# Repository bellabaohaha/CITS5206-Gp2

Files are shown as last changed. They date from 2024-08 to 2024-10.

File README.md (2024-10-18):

# CITS5206-Gp2

The team predominantely used [Github Projects (Issues)]([url](https://github.com/bellabaohaha/CITS5206-Gp2/projects?query=is%3Aopen)) to document the provisioning, development, and testing of the solution as this was predominantly a hardware and cloud based project to keep the documentation consistent and source of information centralised. A client demonstration was completed and a report was created and sent to the client directly.

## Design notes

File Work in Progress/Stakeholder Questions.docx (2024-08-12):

# Stakeholder Questions

1. What is your current solution for soil compaction?
- Prompts: Do you send someone to the field to manually monitor or is there any other source of “ground truth”.
- Why: Eventually we may want to test and validate results for effectiveness and/or accuracy of IoT solution. Can also compare (time trial) how long the alternative takes
2. Do you currently track how much time you spend measuring soil moisture or dealing with the fall out (bogged equipment) of the effects of soil compaction?
- Why: So we can find out how much time, resources it takes, how often it occurs and good point of comparison. Goal is not to create more work when solving the problem.
3. Do you foresee any challenges with implementing IoT solution?
- Prompts: Would you be ok with dispersing these sensors. If an IoT solution is provided, can you place them so that your existing equipment will not ‘run over’ them.
4. When you open the map on John Deere Platform, for each paddock we imagine there will be multiple IoT Sensors, currently we’re thinking of sending through the Location data of the sensor and the last reported Soil Moisture level (early morning or midday).

Would you also like to have a recommendation on the John Deere Dashboard that suggest whether it’s safe to operate heavy machinery or not?

- Why: User Experience information so that we know what information is required and how best to display it. See Example below.

Example from John Deere Platform - Source (https://developer.deere.com/dev-docs/assets)

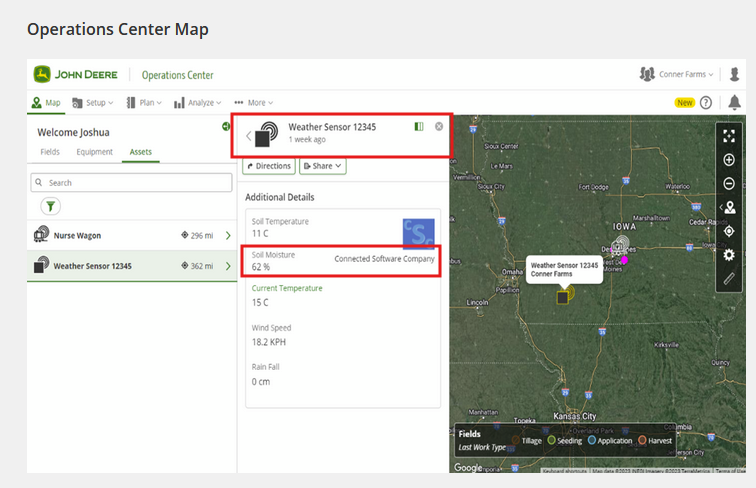
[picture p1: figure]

5. At this stage or any other stage of the project do you have any comments or things that we need to consider or any challenges that we may need to solve?

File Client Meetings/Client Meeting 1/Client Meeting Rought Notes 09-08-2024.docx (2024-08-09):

Agenda for Meeting:

1. Review John Deere Platform

Questions:

  a. What does the platform look like for the user

Farm, different paddocks and geometries. All equipment has telemetry data.

Decision support system. Every operation i.e. sprayer is shown on platform. Developer options has machinery and sensors. Goal is to have environment other sensor to platform and link it. And Display on the map. (Map section of Operations Center). Sensor streams data. Need to send an email

Telemetry data with real time RPM, fuel, idle time, time working under Maps.

One data under a team -> Setup has data.

Make a UWA account and send that through today.

Get letter from Atif and Gustavo if required.

Data is stored in ShapeFiles GIS data. Geometric

Target Rate -> Required rate of soil moisture, does that change over time over different prases

Manipulate through Irrigation System. Target rate from point of view. They used to sow seeds when there was rain, now they sow when dry, because they want optimal window of growing crops. Changing soil moisture in clay soil particularly in soil compaction problem

13-14% of WA has clay soils -> This is why soil compacts. Action: Pressure, deforms soil. Depends on resistance of terrain (sandy, clay) weight of equipment and down force is major factor. Large equipments (farm machinery western Australia)

Heavy machinery : Bourgalt heavy seeder – 17 tonnes without seed and fertiliser. They control it with trend lines and always be on the same track. Also waterlogging. Waterlogging can be visible and the effects can last even after the visible water level decreases. So we need to reach the right moisture level threshold. Top level of soil is sand, second layer is clay and the water gets trapped between two layers

Communication from sensor to API

John Deere has rainfall in mm, API for BOM available, PERSIANN CDR NOAA (out of scope) Package from Python or R package with deeper network of weather stations

GIS for geometry geo-fencing

Requirements for sending time based:
1. Twice a day

2. Early in the morning (stop for lunch)

3. Sampling rate (once an hour takes a reading)

4. Send through what we think requirement are

5. Areas we are covering, problem statement and quantification of impact. Get feedback

Next Steps:
1. Developer Account

2. Setup geo-fencing (GIS) and adding network

3. API

4. Send message to Rachel regarding network

5. LoRa limitation (mesh network using local raw LoRa with NB-IoT with a gateway)

Third parties currently source data from platform, process and send back to platform – we could use this for interpolation of the soil moisture data.

  b. What does landing page look like
  c. How would they normally check their assets
  d. Can you integrate other applications, ‘views’ or dashboards
  e. Besides operations do they manage anything else – trying to see if there is an opportunity for value add i.e. can we integrate with existing BOM rainfall data as a benchmark. OR do they manually collect the soil moisture that they want to view on the platform
2. Discuss questions we have for Farmer
- Ask Hani what we wrote down
3. Feedback for work we have completed
- Have them showcase in 1-2mins what they have done so far, get any feedback
  - David – Problem Statement
  - Bella – Quantifying Impact
  - Uday/Dharani – Initial Research into components
- List of Requirements 1. Number of Devices -?

2. Maximum and minimum distance between devices

3. What information is gathered and how often?

4.

- Solution Components:
1. Overall Considerations:
  a. Authentication of device
  b. Encryption (at rest vs in transit)
  c. Device and Software Setup + Calibration (Testing and Validation)
  d. Maintenance
  e. Deployment
  f. Retrieval
  g. Disposal
2. Physical Hardware Device:
  a. Soil Moisture Sensor(s)
  b. Microcontroller
  c. Power Storage
  d. Power Management
  e. Power Generation
  f. Communication Transceiver (how do we decide which one) – depends on transmission/communication pipeline
3. Transmission Pipeline (can we create a diagram, horizontal axis
  a. Between devices (node to node)

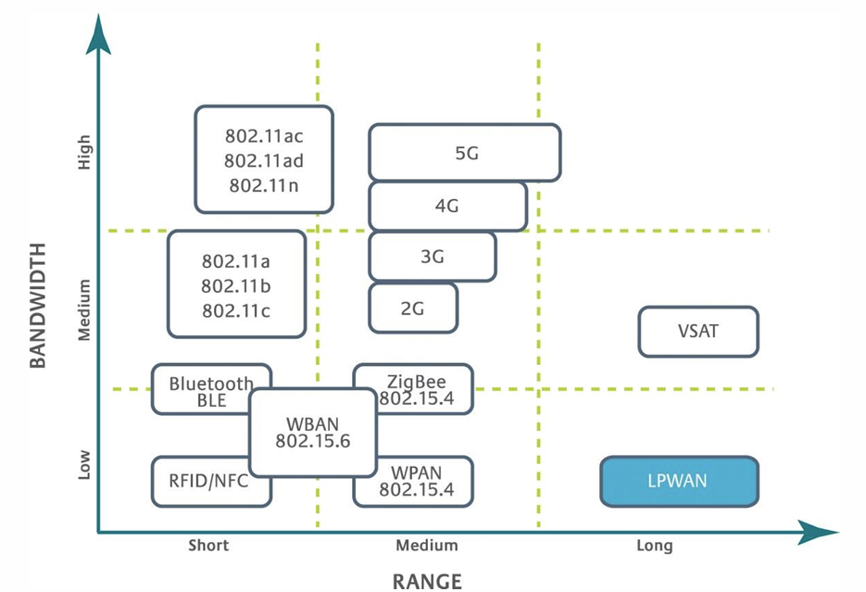
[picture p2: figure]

4. Discuss any bottlenecks or uncertainties
5. Discuss next steps
6. Book in next meeting

Handover and Post Handover Considerations

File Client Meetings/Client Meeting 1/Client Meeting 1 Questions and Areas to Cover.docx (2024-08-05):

Introductions

Gustavo – Rapid prototyping, sensing, agriculture

Wesley (Wess) – background as mechancial and technology sensors

Atif – Mainroads, bridge health monitoring

Highlight Risks

Don’t have anyone with an electrical, mechatronics, mechanical and agriculture background

Project Overview
After minining oil and gas, agriculture largest industry in WA

40% of grain exports comes from WA

Access to bunch of farmers.

Farmer needs to do bunch of operations during growing season

Problem: cannot operate heavy machinery during rain due to compaction + bogged

Average farm size is 6000 hectres

When it rains heavy machinery has issues – no real time monitoring in Satellite currently

Current solution – person on ground checks ground to see whether they can do their farming process with their machinery

Sensor requirements:

Soil monitoring at different depths, when a level of moisture is reached it sends a message

Constraints: Ruggedised sensor, calibrated for different types of soil, measuring conductivity (different soils influence calibration). LORA equipment run for scientific purposes are quite expensive. Any equipment is minimum $700, as we need to have multiple sensors especially in water logged areas. Current smart agriculture solutions are being offered by one platform for decision support service (John Deere) - can access their API etc.

What we need is a real time soil monitoring system + Dashboard and integrate with John Deere API – within the same platform. Still to decide on the sensor, it is quite complex. Each real time monitoring system will have multiple sensors at different depths. We need to focus on communication network, low power sensor and the integration as the sensor itself and ruggedising it is something that will have to be looked at with a team with proper capabilities.

Constraint is Time and our Capabilities - Major Milestones:

1. Project Specification – Lock in Meeting in Week 4 for feedback
2. Final Project Demonstration and Report – Lock in Meeting in Week 10 for demo and report

Action Steps

Find Challenges ushc as

- Integration with John deere API
- Capture soil moisture at different depths
- Managing power - low power
- Communication inside the ground
- Thesis
- Edge Computing (Farmer’s house, cellular connectivity), what type of data has to be
- What John Deere API payload looks like
- Dashboard User interface – is it a RAG indicator for point in space (GPS location) soil moisture, is it a reading of soil moisture, is there interpolation between sensors

Deliverable:

Overview of Design and Requirements

Document in a way it built upon

Power, appropriate microcontroller, What the data looks like, Commuication of it, and basic Protoype focus is Wireless Network, Power, and integrating to John Deere API

Focus on Design with small prototype and Simple soil moisture sensors

Define the requirements, then timeline and requirements

How to best communicate the dashboard output (user interface) on John Deere Platform – talk to a real farmer

Problem of finding the sensors and then also running over it etc.

John Deere Platform Farm to see how it works – Gustavo

Basically device sends telemetry data

Geospatial information and interpolation (need to consider this). Point based information for sensor, surface (inverse distance way so if 50 + 35, divide between it)

Overview of the problem, all the things we want and then perhaps a demonstration of a part of it with a basic prototype. Focus on project requirements. Defined documentation is also important

Before Next Meeting

- Goals
- Timeline of research
- Stakholders, and look at John Deere sensor (find out what it looks like on the dashboard)
- Research on communication tehcnology
- Required, every week: Send weekly update of what we have done

## Meeting Preparation:

Introductions

Go around table and understand everyone’s background and what their expertise is, so we know who might be the best person to contact for a particular issue or area of knowledge.

Client Role and Expectations

1. Roles – what are your roles for this project
  a. How involved do you want to be in the project development process? Can we do some research, get some feedback and iterate?
  b. Are there any other stakeholders we need to engage?
2. Expectations for meetings – Availability, Time
3. Communciation preference - Email and/or F2F/Teams Workshop
4. Expectation for final deliverable – What does it look like? One Soil Moisture monitoring system with some sensors, microcontroller, battery that sends data using a communication protocol to eventually connect to the internet and update a live dashboard to show insights into soil moisture and maybe make a recommendation based on a threshold or value?

Constraint is Time and our Capabilities - Major Milestones:

3. Project Specification – Lock in Meeting in Week 4 for feedback
4. Final Project Demonstration and Report – Lock in Meeting in Week 10 for demo and report

Project has a bit of breadth and depth. Goal is to provide you something valuable. Is this a prototype or an MVP? Because if we did it right and considered all the elements MVP will require significantly more time than time allows for. We could identify all the elements that we cannot complete and add into future works

Understanding Client's Needs and Expectations

1. Project Scope and Objectives:
  - What are the main goals of the soil moisture monitoring system?
  - Are there specific features or functionalities that are essential?
2. Current Practices and Challenges:
  - How do farmers currently monitor soil moisture?
  - What challenges do they face with the current methods?
  - Besides what is in the brief are there any specific problems related to soil compaction that need to be addressed?

Technical Requirements

3. Data Requirements:
  - What specific data points are crucial for effective soil moisture monitoring (e.g., soil moisture levels at various depths, temperature, humidity)?
  - Is there any analysis or transformation of data like an equation or something for soil moisture?
  - How frequently should the data be collected and reported?
4. Sensor Selection:
  - Are there any preferences or restrictions regarding the types of sensors to be used (e.g., cost, durability, accuracy)?
  - Are there specific depths at which soil moisture needs to be measured?
5. Environmental Considerations:
  - What environmental factors should be considered (e.g., waterproofing, resistance to rust, temperature range)?

Communication and Data Management

6. Read Omar’s paper before on Communication Technology, wanted to clarify:
  - Communication technology really depends on payload (data size). What communication technologies are feasible for transmitting data from the sensors to the local hub/server and then to the internet? NB-IoT or LoRAWAN might be easiest
7. Data Integration and Dashboard:
  - What attributes and metrics should be included in the dashboard?
  - Do you have any prefererence on how the data should be visualized to provide actionable insights for farmers?
  - Did you want us to integrate anything else into the dashboard – see link in my research

Cost and Implementation

8. Budget Constraints:
  - Are there any budget constraints or funding considerations for the project?

Analysis and Testing

9. Testing System accuracy and robustness:
  - I found capactative soil moisture sensor requires calibration etc. that will take time.
  - Hard to do this as we need commercial sensors – see research (we can simulate)

Miscellaneous

9. Regulatory and Compliance Issues:
  - Are there any regulatory requirements or compliance issues that need to be considered? E.g. we have to go off site to test or something

Clarifying Soil Compaction

- Ask about the relationship between soil moisture and soil compaction:
  - How do they currently measure or assess soil compaction?
  - Are there existing technologies or methods they use to monitor soil compaction?

Example Sensors and Technologies

- Discuss potential sensors and technologies that could be used from researc:
  - Capacitive or resistive soil moisture sensors for measuring moisture at different depths.
  - GPS modules for location information.
  - Wireless communication modules (e.g., LoRa, NBIoT) for data transmission

Summary of Meeting

Action Steps

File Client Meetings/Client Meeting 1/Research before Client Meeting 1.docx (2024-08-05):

Communication Paper Takeaway:

- Communication Protocol will probably be LoRaWAN or NB-IoT
- Really depends on the data that is being collected and transmitted

Waterlogging article:

- Costs approx $50M a year
- Issue for productivity
- Quite a complex problem, really still didn’t fully understand it
- There are existing solutions

John Deere Website:

- APIs available but not really specific e.g. weather station asset, environment etc.
- Need to clarify with Atif what he wants us to focus on here, is it an example JSON payload?

https://developer.deere.com/dev-docs/assets#type-table

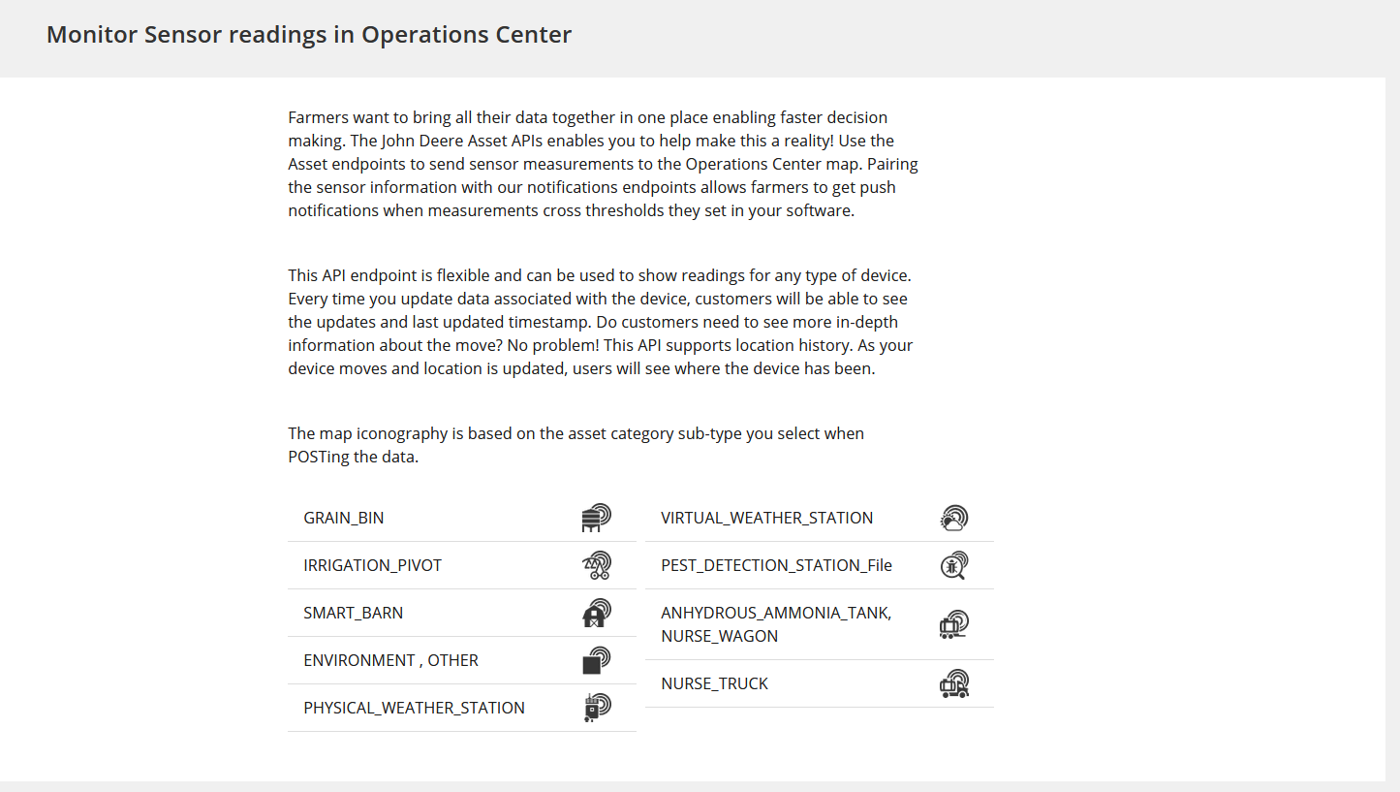
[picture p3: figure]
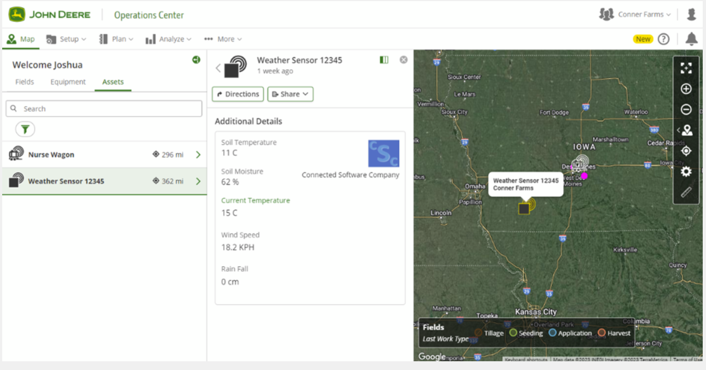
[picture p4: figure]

My Research

Article supporting usefulness of satellite soil moisture monitoring: https://www.mdpi.com/2072-4292/14/16/3971

Other estimates/sources for soil moisture:

1. Since 2021 - https://www.tern.org.au/news-smips-soil-moisture/; I think it’s ML derived fusion (Data assimilation) model. https://shiny.esoil.io/SMIPS/

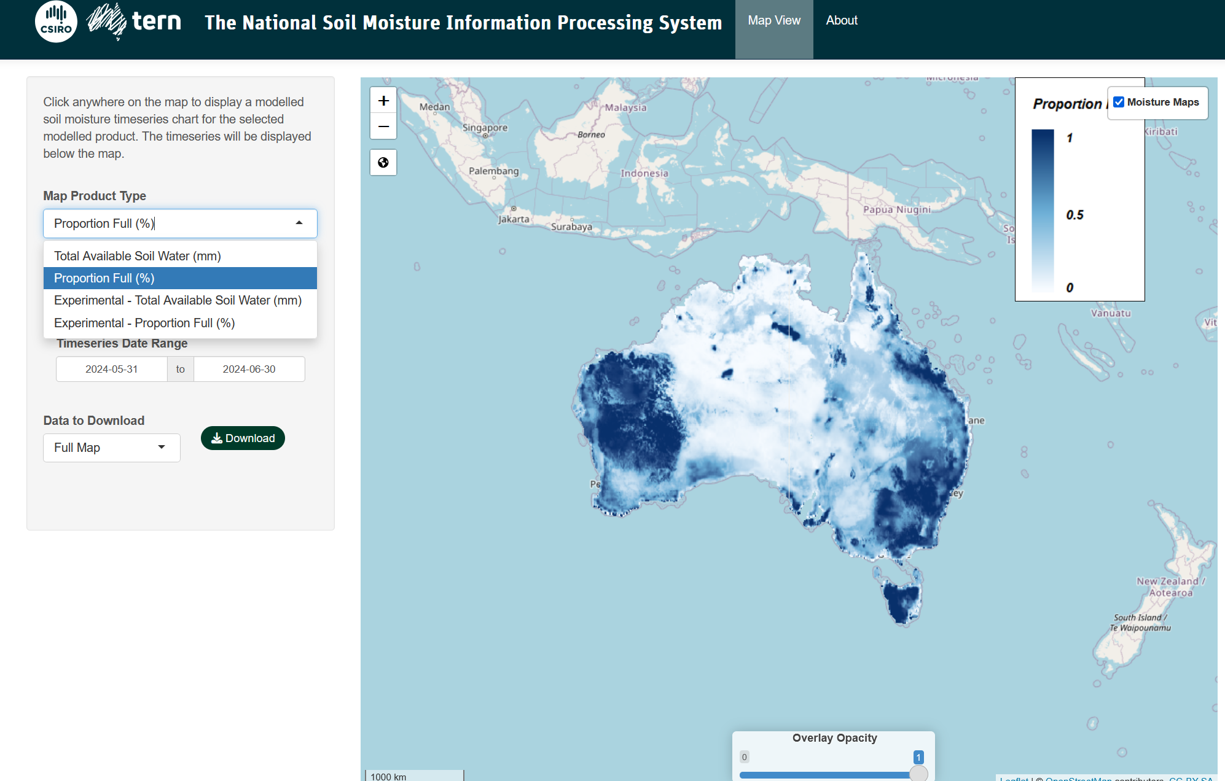
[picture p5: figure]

2. https://awo.bom.gov.au/products/historical/soilMoisture-rootZone/5,-27.489,134.231/nat,-25.609,134.362/r/d/2024-08-01

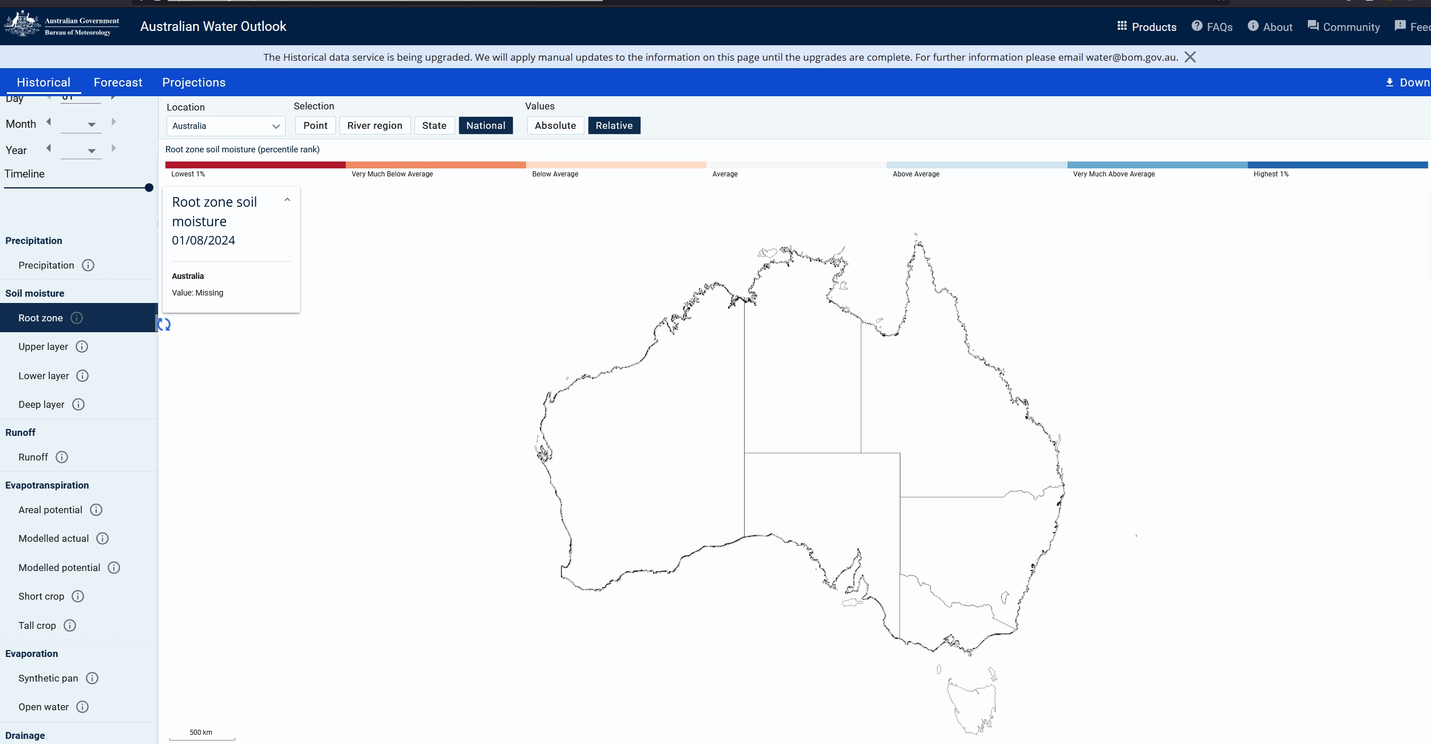
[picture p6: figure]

3. https://ausenv.tern.org.au/aex/#/2023/Soil_moisture/Region/Actual/Local_Government%20Areas/bar,options/-31.86/116.54/8/none/Roadmap/Opaque

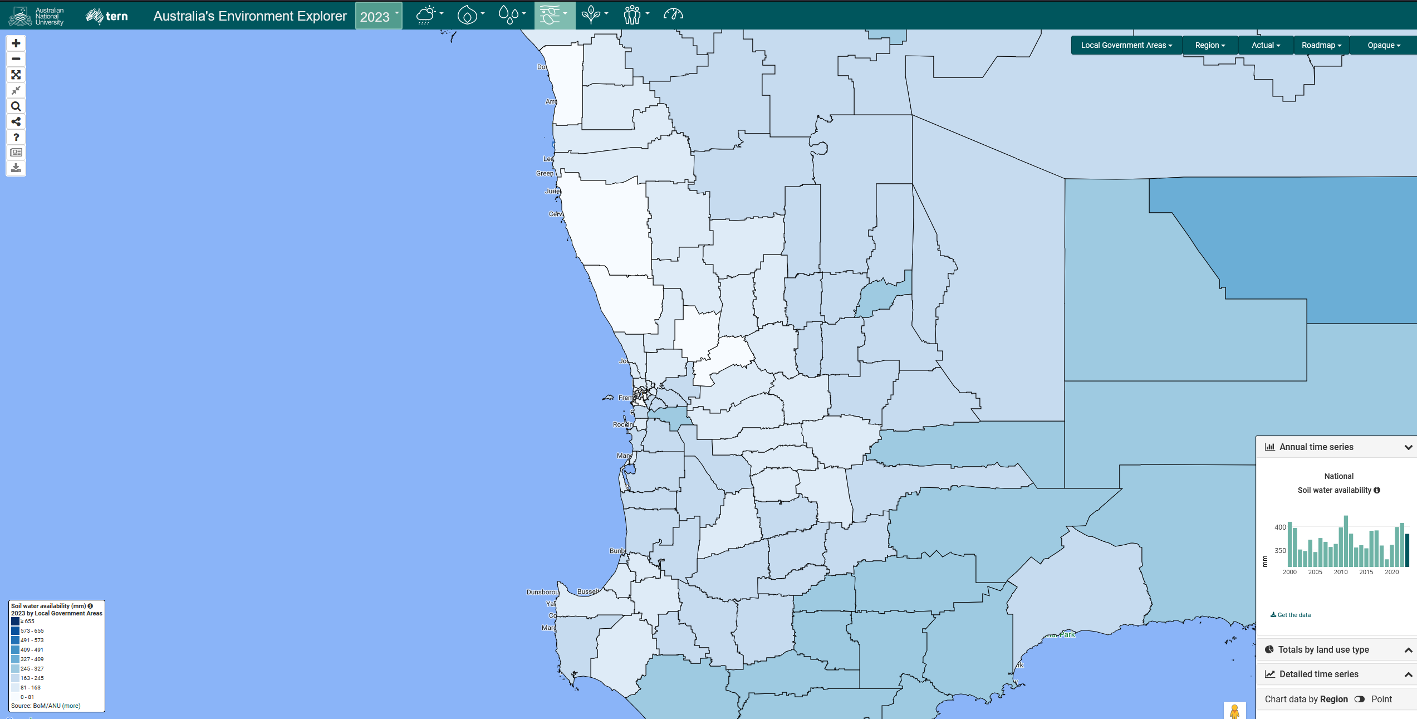
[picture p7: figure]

Appparently capacitative soil moisture sensors are better because of galvanic effect?

https://forum.arduino.cc/t/looking-for-a-proof-that-soil-moisture-sensors-can-be-reliable/662749

Found some resources for capacitative sensor:

How do capacitative sensors work? https://hackaday.com/2021/05/17/soil-moisture-sensors-how-do-they-work/

Useful resource in explaining the technical details (calculations) https://www.biomaker.org/block-catalogue/2021/12/17/soil-moisture-sensor-aideepen-v12

Actual resources to buy capacitative soil moisture sensors:

https://core-electronics.com.au/catalogsearch/result/?q=Capacitive%20Soil%20Moisture%20Sensor

https://core-electronics.com.au/capacitive-soil-moisture-sensor-corrosion-resistant.html

https://core-electronics.com.au/sensors/soil-moisture.html - IP68 but expensive @ $50

https://core-electronics.com.au/gravity-analog-waterproof-capacitive-soil-moisture-sensor.html - Waterproof @ $31.50

Need to do further research if client agrees into whether we need any type of middle component/interface to connect to the microcontroller?

Do we need to also record soil temperature?

https://typeset.io/questions/what-the-effects-of-soil-temperature-on-soil-compaction-3vdq7ggioy

Microcontroller: GPS module inbuilt into TTGO T-Beam: https://www.lilygo.cc/products/t-beam-v1-1-esp32-lora-module, advanced power management

Housing for components, microcontroller:

https://www.matterhackers.com/articles/the-best-3d-printing-filament-for-outdoor-use

Can we simulate UV resistant housing?- I have a 3D printer with PLA+ which is not UV resistant but has a higher resistivity to the elements

Testing Difficulty: https://www.ncbi.nlm.nih.gov/pmc/articles/PMC10007478/

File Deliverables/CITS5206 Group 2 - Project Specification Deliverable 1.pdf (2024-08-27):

PROJECT TITLE: Development of cost-effective soil moisture monitoring system for Broadacre Cropping
CLIENT: The University of Western Australia (Atif Mansoor & Gustavo Alckmin)
GROUP 2 MEMBERS: Asad Maza (21211711), Bella Bao (23843181), Dharani Kumari Nagali (23870369), David Shang (24071326), Hanni Bao (23888818), Udaymithra Kalla (23858856)

AIM AND BACKGROUND
Soil moisture is crucial for agricultural productivity, especially in regions like South West Western Australia, where clay soils and compaction issues hinder water infiltration and root growth. Traditional manual testing methods for soil compaction are labor-intensive and slow, while satellite-based solutions lack real-time data and adequate resolution. This project aims to address these challenges by developing a simple physical prototype focused on communication, data storage, and visualization. The prototype will serve as a foundation for future development, allowing for expanded functionality and optimization to meet comprehensive project requirements. Due to limited time, team capabilities, and resources available, this stage of the project is to show feasibility of a soil moisture monitoring system with a focus on documentation, power management, a visualization dashboard and provide an API Payload structure that aligns with John Deere API assets.

KEY BENEFITS
Optimized machinery operations, integration with existing systems, and improved crop yield and irrigation efficiency. Real-time soil moisture data enables farmers to effectively schedule machinery use, preventing soil compaction, crop damage and bogged machinery. Our solution should integrate with current management platforms, simplifying decision-making for machinery operation, irrigation and harvesting. Continuous soil moisture monitoring supports data-driven machinery operations, irrigation, thus enhancing water use efficiency and boosting crop yields.

DELIVERABLES
This project's goal is a feasibility study to develop a solution for monitoring soil conditions in Western Australia's broadacre cropping industry with a focus on building a solution that can serve as a foundation for future phases as the scope is large and timeframe should be over multiple years. By using IoT technologies, the project enhances data-driven decision-making and optimizes farm management practices.

Key Deliverables:
1. Project Documentation: Develop a comprehensive report that covers our current phase and future areas to consider across the project lifecycle. Contents will include defining the problem, current phase solution development and other key areas that need to be explored eventually to deliver and deploy a robust remote real time soil moisture monitoring solution.
2. Soil Moisture IoT Prototype : Our prototype is there to demonstrate the capturing of soil moisture data, power management and will consist of a microcontroller with three soil moisture sensors, power management with sleep cycle/duty cycle functionality, and node-to-gateway communication using LoRa communication.
3. Gateway Communication and Cloud Storage: Gateway will receive the data from IoT Prototype and transmit data to a scalable cloud platform storage service using the Internet.
4. PRIORITY 1 - Insights and Analytics Visualization Dashboard: A simple analytics and visualization dashboard connected to cloud platform storage, enabling near real-time monitoring and visualization for users to make data-driven decisions and track key performance indicators. We have provided a live PowerBI prototype dashboard as an example (Appendix).
4. PRIORITY 2 - John Deere API integration: Our goal is to develop a structure of the payload for API Assets that aligns with John Deere API requirements as the MVP. If time permits, we will showcase successfully sending data from DynamoDB to John Deere Platform.

PROPOSED METHODS
As the scope of the project is large, we will be relying on the hyperlinked guides in the Solution System Components Section and diagrams in appendix of this report, with the Gantt Chart (Appendix) and client feedback to prioritize and develop particular areas of the deliverables.

Task 1: Project Documentation: The documentation will include background on the current problem including the impact on South West WA. The goal is to produce a document that shows the development of the prototype Soil Moisture Monitoring system in the current phase so that it can serve as a foundation for future teams to build upon in future phases. Initially, we’ll create a report structure and share it with the client with Sections and subsections of the document contents. Once we have feedback we will add contents to the document, in parallel to the other tasks. An important section to include is the ‘Future Works’ section of areas identified by us and the client that need to be explored in future phases.
Task 2: Soil Moisture IoT Prototype
In this phase of the project, we will develop a simple prototype focusing on selecting a microcontroller and appropriate communication protocol for transmission of soil moisture, TimeDate, and GPS data. We’ll have a power management system for optimized sleep and duty cycles; and three simple soil moisture sensors to measure and ‘mock’ soil moisture readings at three different depths. This will transmit moisture data using LoRa to a Gateway. We’ll use an iterative development process based on client feedback. If time permits, we’ll include demonstration of multiple Soil Moisture IoT Prototypes connecting to the Gateway.
Task 3: Gateway Communication and Cloud Storage
Gateway will connect to the Soil Moisture IoT prototype and transmit the data to the internet to a cloud provider platform that supports cloud storage. Gateway receives data from IoT system(s) through LoRa communication and temporarily stores: soil moisture data at three depths per Soil Moisture IoT prototype (including TimeDate, GPS location). The gateway will append the payload it receives with its own metadata (GatewayID, GPS location, transmissionTime) then send the data to the cloud provider for processing and storage which will then serve as a data warehouse for other operations such as integration with Visualization dashboard. We will develop this iteratively with the client in parallel with Task 4 as they are dependent.
PRIORITY 1 - Task 4: Insights and Analytics Visualization Dashboard
We will create a visualization dashboard to provide near real-time insights and analytics. It will show historical data of Soil Moisture levels in the current phase. This can be used to analyze other key performance indicators of farming/agriculture in future phases, e.g. crop yield, water usage in Irrigation. We will display points in space soil moisture data at different depths. After we achieve this and if time allows, we will use data interpretation methods like Angular Distance Weighting (ADW) to interpolate soil moisture levels at different depths and geographic locations. We will use an iterative development cycle based on client priorities. Goal is that users should be able to see the near real-time data and make prompt data-driven farming decisions.
PRIORITY 2 - Task 4: John Deere API Integration
We will create a payload structure based on Assets API (https://developer.deere.com/dev-docs/assets) as MVP initially based on ‘IoTSystem’ and ‘LoRaGateway’ entities in Prototype UML Class diagram (Appendix). If time permits, we will connect DynamoDB with the John Deere Platform.

APPROACH TO PROJECT SPECIFICATIONS AND SOLUTION DESIGN
The deliverables, project timeline, Solution System Components, and IoT prototype components has been designed considering and balancing the following considerations:
- Client Budget: At prototype stage, we use existing UWA resources. If more materials e.g. sensors are required, we will list and breakdown the costs for future phases.
- Client Priorities: This phase of the project should be able to be used in future phases -breaking down the system into components that can be swapped out if required and noting down ‘Future Work’ to be addressed in future phases.

- Project Risks: Scope of the project is large and time is limited, we will manage the scope through the Gantt Chart and open communication with the client on our progress.
- Team Capabilities and Experience: Team experienced in Front End Web Development and limited Back End experience of deploying Web Apps on local machines. One member with some cloud deployment experience. For example, sensor selection and ruggedisation is out of scope for this phase.
- Team Areas of Interest: Majority of members want to develop their data analytics and data visualization capabilities.

SOLUTION SYSTEM COMPONENTS
For all technical deliverables, we created a Solution System Components and Dataflow Diagram (https://github.com/bellabaohaha/CITS5206-Gp2/blob/main/Deliverables/IoT%20Soil%20Moisture%20Monitoring%20System%20-%20Feasiblity%20Study%20Data%20Flow%20Diagr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) that shows the system components and specific communication methods required to deliver this phase of the project and that are used in our STRIDE analysis.

Components description and justification:
IoT Prototype: MVP to showcase feasibility of project with a focus on power management, LoRa for communication of soil moisture and GPS data over long distances up to 15 kms to a Master Node. Master Node (Internet Gateway): Eventually data needs to be transmitted to the internet, Master Node is responsible for receiving data from IoT Prototype and transmitting to AWS IoT Core using MQTT over HTTP which is a secure protocol.
AWS IoT Core: Selected because its designed for resource constrained devices and suitable for large scale IoT Deployment and Management which should be useful for future phases. Also supports MQTT (https://how2electronics.com/connecting-esp32-to-amazon-aws-iot-core-using-mqtt/) and LoRaWAN if required. An AWS IoT Core Rule (https://docs.aws.amazon.com/iot/latest/developerguide/iot-ddb-rule.html) will be used to send data to the AWS DynamoDB table.
AWS DynamoDB: NoSQL fully managed database, flexible, suitable for high frequency of data and scalable. Supports code first approach and adding attributes easily compared to relational databases. Priority 1 - AWS QuickSight: As the data is stored on AWS ecosystem, the most powerful visualization tool is AWS QuickSight, it can also integrate with third-party APIs and data external to AWS platform. We will connect DynamoDB table (https://aws.amazon.com/blogs/big-data/visualize-amazon-dynamodb-insights-in-amazon-quicksight-using-the-amazon-athena-dynamodb-connector-and-aws-glue/) using AWS Athena. (https://helicaltech.com/how-to-connect-dynamodb-to-quicksight/)
AWS Lambda: Event-driven serverless function as a service, alternative to an EC2 instance which requires lots of management. We’ll use this to simply demonstrate sending data to John Deere API using HTTP RESTful API and OAuth 2.0. (https://developer.deere.com/dev-docs/assets#/assetCatalog/get) Future phases could use dedicated resources if the number of events warrant dedicated EC2 instances or resources.
Priority 2 - John Deere Platform/API: John Deere Platform will receive data from DynamoDB table (https://medium.com/@bilalashfaq/securing-your-serverless-api-implementing-oauth-2-0-b499e21fb705) and show the data on front end, (https://developer.deere.com/_next/image?w=828&q=75) this platform is a client preference and used by farmers in industry.

APPENDIX
a. Insights and Analytics Visualization Dashboard Prototype: (https://app.powerbi.com/groups/me/reports/1663b1fa-cb7d-43e8-98fa-ab7017c18b4a?pbi_source=desktop) For Client - Visualisation Prototype
b. Soil Moisture IoT Prototype Diagram: (https://github.com/bellabaohaha/CITS5206-Gp2/blob/main/Deliverables/Prototype/Soil%20Moisture%20IoT%20Prototype.pdf) For Client - Diagram of the MVP
c. Soil Moisture IoT Class Diagram: (https://github.com/bellabaohaha/CITS5206-Gp2/blob/main/Deliverables/Ideal%20Solution%20UML%20Class%20Diagram.pdf) For Client - Diagram of Data captured and transmitted
d. IoT Components Selection: (https://docs.google.com/document/d/1XYU6JAHdzzAeZnJyhmISD46vh2zGZKcV/edit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) For Client & Team - Selection rationale, list of components, relevant libraries and guides to develop MVP
e. Gantt Chart: (https://github.com/users/bellabaohaha/projects/3/views/4) For Client & Team - Timeline with tasks, deadlines and team members responsible for development and delivery
f. System Dataflow Diagram: (https://github.com/bellabaohaha/CITS5206-Gp2/blob/main/Deliverables/IoT%20Soil%20Moisture%20Monitoring%20System%20-%20Feasiblity%20Study%20Data%20Flow%20Diagr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) For Unit - Dataflow diagram of entire system solution
g. Preliminary STRIDE Analysis: (https://github.com/bellabaohaha/CITS5206-Gp2/blob/main/Deliverables/STRIDE%20analysis.md) For Unit - Simple prioritized threat analysis of System Dataflow Diagram
h. Project Github Repository: (https://github.com/bellabaohaha/CITS5206-Gp2/tree/main) For Both - Deliverables, Documentation, Code and Prototypes
i. Project Documentation: (https://docs.google.com/document/d/1mFGddaYWOv0TtUflvEK0xnOJ9Dhes-4juftO4dehHdE/edit?pli=1) For Client - Google Document (Work in Progress)
j. Key Stakeholder Matrix: (https://docs.google.com/document/u/0/d/1p9jKdCfmI-gKMEma0tyxOV9yaNjxNzs5mMoTUyz_MWE/edit) For Client - People involved in project and their expectations

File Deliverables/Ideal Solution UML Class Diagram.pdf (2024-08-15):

SoilMoistureSensor

+sensorID: String

+depth: float

+moistureLevel: float

+readMoisture() : : float

+sendMoisture(mcu: Microcontroller) : : void

GPSModule

+gpsID: String

+latitude: float

+longitude: float

+getLocation() : : String

+sendLocationData(mcu: Microcontroller) : : void

Microcontroller

+controllerID: String

+batteryLevel: float

+sensorDataStorage: Map

+locationStorage: String

+storeSensorData(sensorID: String, moisture: float) : : void

+storeLocationData(location: String) : : void

+storeBatteryLevel(batteryLevel: float) : : void

+collectData(sensorData: Map, location: String, batteryLevel: float) : : void

+sendData() : : void

+receiveCommand(command: String) : : void

+goToSleep() : : void

+wakeUp() : : void

SolarPanel

+panelID: String

+capacity: float

+generatePower() : : float

Battery

+batteryID: String

+chargeLevel: float

+providePower() : : float

LoRaTransceiver

+transceiverID: String

+frequency: float

+sendData() : : void

+receiveData() : : void

GatewayMasterNode

+gatewayID: String

+networkType: String

+connectToCloud() : : void

CloudProviderPlatform

+platformID: String

+storeData() : : void

+processData() : : void

JohnDeereAPI

+apiID: String

+sendToJD() : : void

+receiveCommand(command: String) : : void

JohnDeereOperationsCentre

+farmID: String

+paddockID: String

+sendCommand(command: String) : : void

+displayData() : : void

sendMoisture()

sendLocationData()

Charges

Powers

Powers

Powers

Sends and Receives Data

LoRa Data Exchange

NB-IoT/WiFi Data Exchange

Data Exchange

Data Processing | sendCommand(command)

receiveCommand(command)

receiveCommand(command)

receiveCommand(command)

receiveCommand(command)

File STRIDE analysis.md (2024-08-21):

# Preliminary STRIDE Analysis

### Approach and Considerations

We conducted a STRIDE Analysis with a focus on breadth rather than depth, as we are in our project planning phase.

We segmented our analysis based on two key attributes, first attribute is Risk level based on impact of a vulnerability being exploited i.e. criticality of system component and asset value and likelihood of occurrence. Our second attribute is based on when we need to actually ensure the threat is addressed and tested. 

Although our client has not made security their priority, we will provide them the STRIDE analysis with our recommendations so that threats out of our control in our System Design this phase such as Spoofing or Physical Tampering are communicated. Our client can decide on whether they want to resolve this issue and if it's a priority for their needs.

As seen in our solution component diagram and description of our solution, we plan on implementing good communication methods for data in transit such as using MQTT, HTTPS and OAuth 2.0 and secure long-term storage on AWS Cloud Platform.

### Stride Analysis

| **STRIDE Category** | **Threat** | **Impact** | **Risk Level** | **Mitigation Strategy** | **When to Address/Test** |
|---|---|---|---|---|---|
| **Spoofing** | An attacker could spoof the identity of the farmer or the John Deere Platform login interface, tricking the farmer into providing login credentials. | Unauthorized access to the John Deere Platform could lead to control over the IoT system and sensitive data. | High | **Mitigate** - Ask the farmer to enable Multi-Factor Authentication (MFA) for added security. | **Current Phase** |
| **Tampering** | An attacker could physically access the IoT devices and tamper with the data before it is sent to the cloud. | Altered sensor readings could result in incorrect soil moisture data, leading to poor crop management. | Medium | **Mitigate** - Use tamper-evident enclosures for physical devices and employ data integrity checks to detect unauthorized modifications. | **Future Phase** |
| **Repudiation** | A farmer or attacker could deny having sent specific commands or accessed certain data within the John Deere Platform. | Lack of accountability could complicate troubleshooting and auditing. | Low | **Mitigate** - Ensure comprehensive logging and require user consent for actions. | **Future Phase** |
| **Information Disclosure** | Sensitive information could be leaked during transmission between IoT systems, Internet Gateway, Cloud Provider, or John Deere Platform. | Disclosure of sensitive data could lead to privacy violations and competitive disadvantages. | High | **Mitigate** - Use OAuth 2.0 to prevent MITM attacks, and employ strong encryption protocols (e.g., TLS) for secure data transmission. | **Current Phase** |
| **Denial of Service (DoS)** | An attacker could flood the Internet Gateway or LoRa communication channel with excessive traffic, disrupting the flow of data. | Disruption could prevent real-time soil moisture data collection, leading to delayed or incorrect farming decisions. | Medium | **Transfer** - Employ a third-party DDoS protection service. | **Current Phase**  |
| **Elevation of Privilege** | An attacker could exploit a vulnerability in the John Deere Platform to gain unauthorized administrative privileges. | Disruption of operations or access to sensitive data. | Low | **Mitigate** - Apply strict access control, regularly patch vulnerabilities, and enforce the principle of least privilege. | **Current Phase** |

### Conclusion
We will review the diagram again at a later stage in the project for our individual assessment. Reviewing our preliminary STRIDE analysis will be helpful as our System Components may change. 

Ultimately, as IoT devices are resource constrained, implementation of robust information security techniques listed in [OWASP](https://owasp.org/www-community/Threat_Modeling_Process) in our design is limited. We also considered other constraints out of our control such as $0 budget that limits our ability to solve certain issues using the most effective methods such a third party Denial of Service Protection or Physical Security Housing for devices to ensure IoT devices are secure.

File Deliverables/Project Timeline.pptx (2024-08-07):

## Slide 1

Project Timeline

Activity

Week

August

32

33

34

35

September

36

37

38

39

40

October

41

42

Remark

Initial Client Meeting

2/08/2024

Project Kick off

Problem Scoping and Solution
Components Prioritisation

Solution Components Research

5/08/2024 - 9/08/2024

Dependent upon time, resources
and skills

Research into prioritised
components of solution

Initial Mock Up/Demonstration
and Feedback

Feedback Implementation and
Project Specification Report

12/08/2024 - 15/08/2024

Development update with
prototype of some functionalities

16/08/2024 - 22/08/2024

16/08/2024

23/08/2024

Submission of Project
Specifications Report

Iterative Development of
Solution Components

23/08/2024 - 4/10/2024

Implementation of
Solution components

Documentation of Solution
Components and Report Feedback

7/10/2024 - 17/10/2024

18/10/2024

Documentation and
Identifying Future Work

Final Demonstration,
Presentation and Handover

Final MVP, Feedback
and Handover

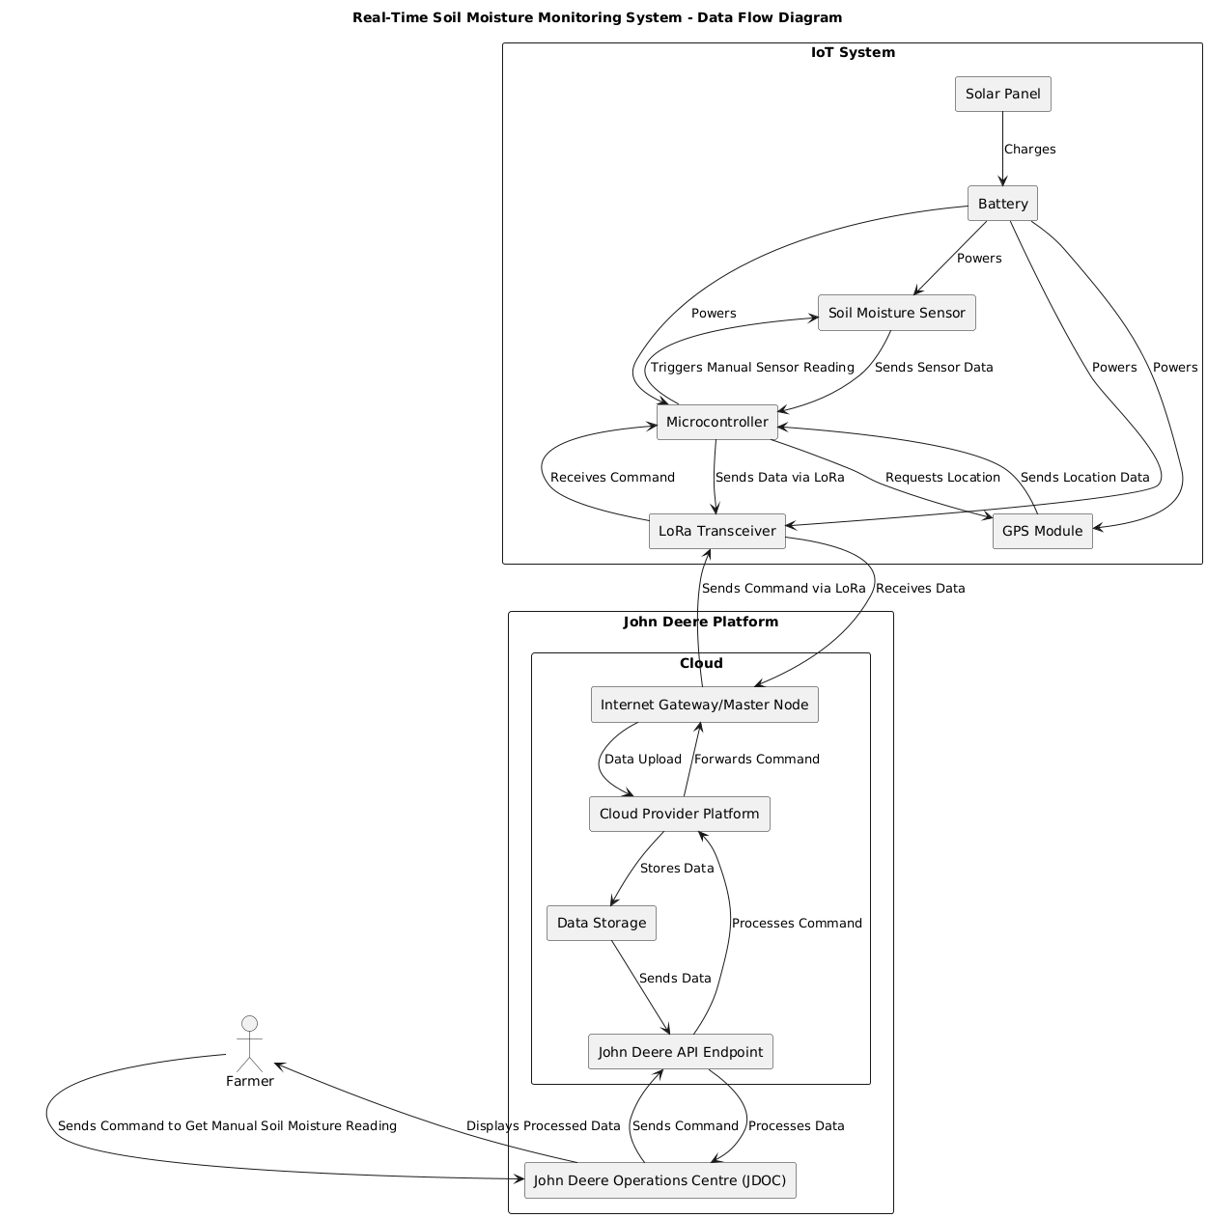
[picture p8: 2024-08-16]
Deliverables/Ideal Solution UML Dataflow Diagram.png

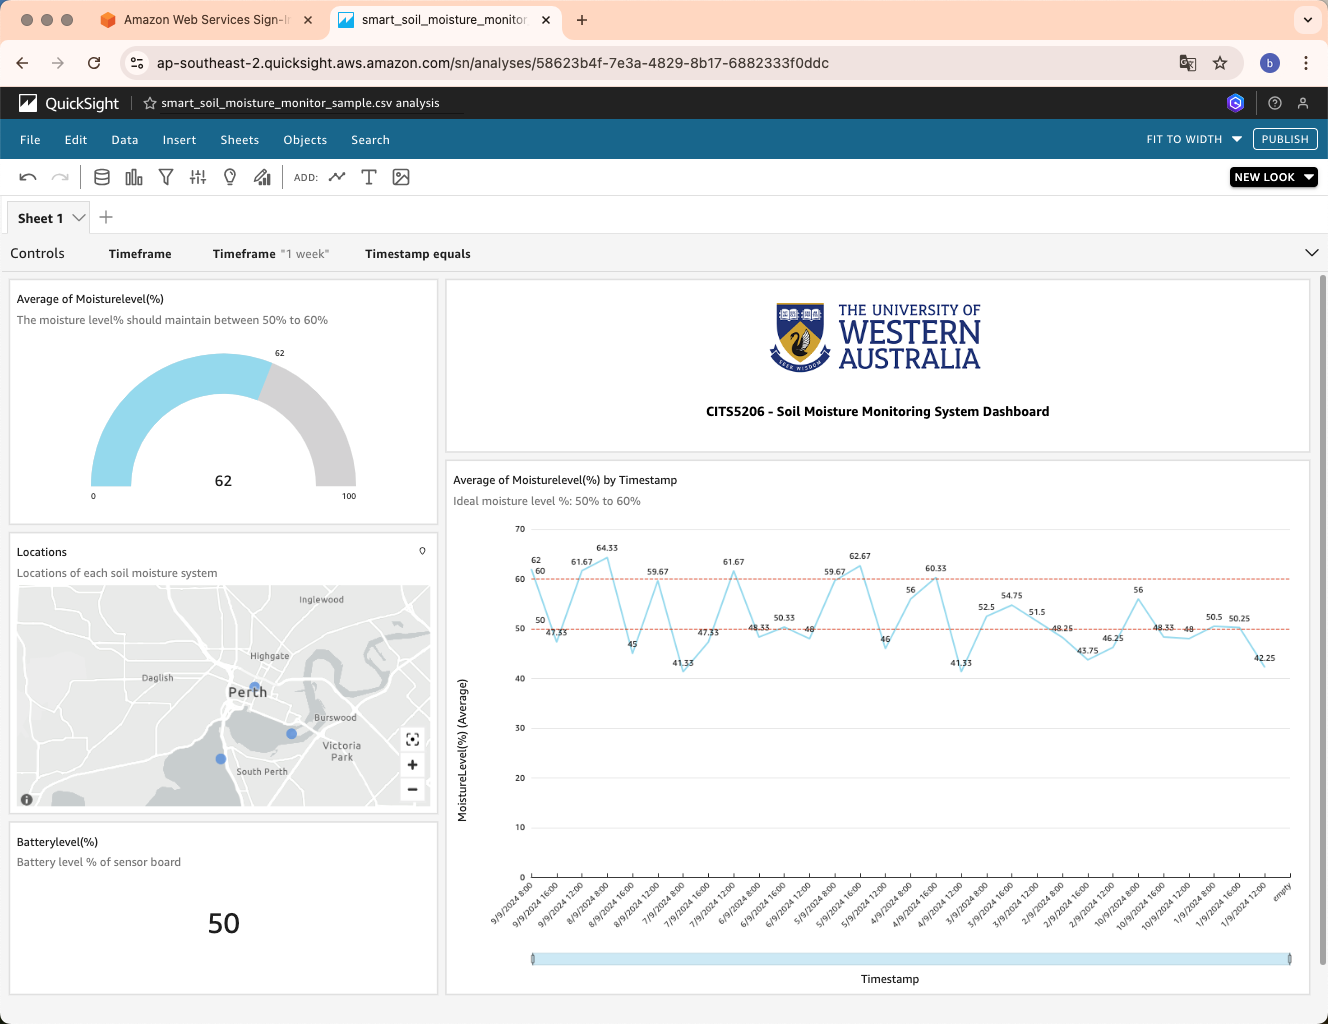
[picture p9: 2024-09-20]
Deliverables/Quicksight/quicksight.png

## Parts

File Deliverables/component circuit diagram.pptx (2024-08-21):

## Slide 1

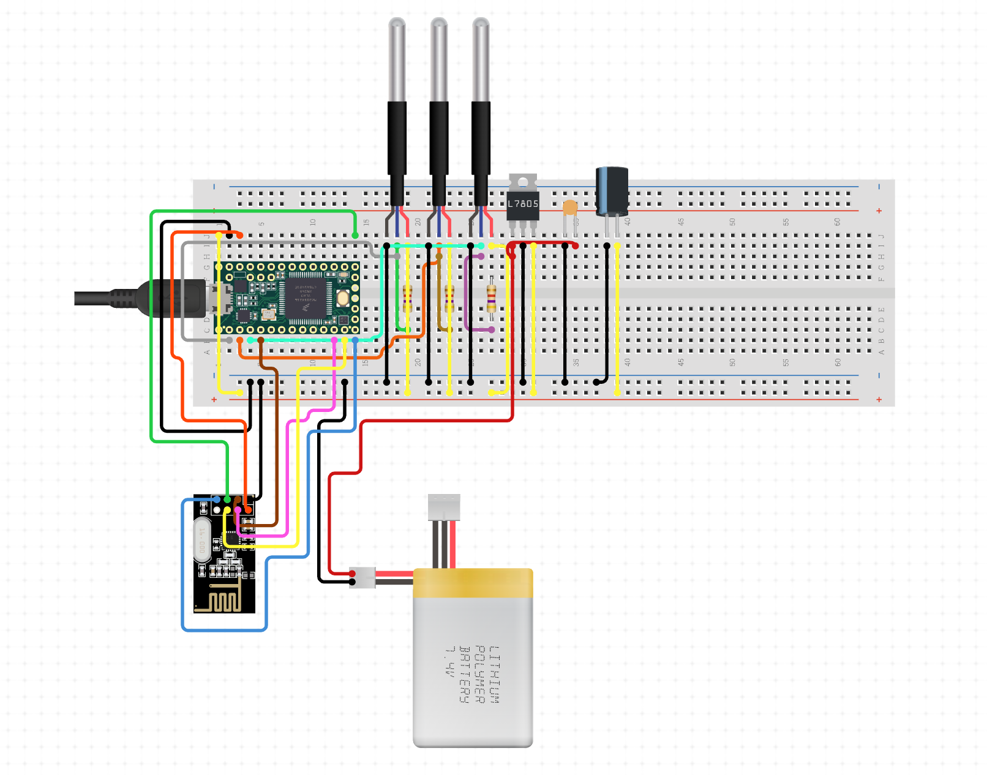
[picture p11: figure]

Moisture sensors x3

TTGO

LoRa

Lithium Battery

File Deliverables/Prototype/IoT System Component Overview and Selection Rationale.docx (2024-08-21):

IoT System Component Overview and Selection Rationale

Considerations and Constraints

The selection of components for the Soil Moisture IoT Prototype and the LoRa Gateway based off the following considerations and constraints:

1. Budget Constraints: With a $0 budget, all components must be sourced from existing supplies at the University of Western Australia, meeting requirements of the problem while balancing functionality.
2. Compatibility: Components are chosen for their compatibility with each other, reducing integration complexity. TTGO T-Beam, with its integrated features (LoRa, GPS, ESP32), serves as the system's core, and other components are used to build the rest of the system.
3. Flexibility and Scalability: Selected components are versatile and cost effective, allowing for easy swapping or upgrading if needed. For example, while capacitive soil moisture sensors are used for this current phase prototype, in future phases more precise sensors can be integrated without significant changes to system architecture.
4. Power Management: Critical aspect of the design requirements is low power consumption. Components like 18650 Li-ion battery and the TTGO T-Beam are selected for their ability to support long operation times with features like sleep cycles and selective activation of modules (e.g. GPS).
5. Documentation Availability: Each component has extensive documentation and strong community support, crucial for troubleshooting and ensuring the project’s success. This is especially important in this project where time and team member’s expertise in IoT are limited.
6. Client Preferences: We considered client preferences when selecting components. Consequently, we selected boards that have long range communication modules with built in power management and Soil Moisture sensors are out of scope for this phase and will be addressed in future phases by teams whose capabilities and experience are better aligned and suited for sensor selection.

Specific Component Selection Rationale

1. Microcontroller: TTGO T-Beams

- Integrated Features: Combines an ESP32 microcontroller with Wi-Fi, Bluetooth, LoRa communication, and a GPS module, reducing need for multiple separate components.
- Flexibility: Supports multiple communication protocols, allowing for easy future modifications.
- Low Power Consumption: Ability to enter deep sleep mode and the selective use of the GPS module and LoRa transmission power contribute to efficient power management.

2. Soil Moisture Sensors: Capacitive Soil Moisture Sensor v2.0

- Compatibility: Works well with the Analog (ADC) inputs of TTGO T-Beam.
- Low Power Consumption: Designed for low power operation, suitable for battery-powered systems.
- Adequate for Prototype: For simulating Soil Moisture reading at 3 different depths. Sufficient to showcase for feasibility testing, with option to upgrade in future phases.

3. Battery: 18650 Li-ion Battery

- Capacity and Longevity: Reliable power with sufficient capacity to maintain system operation over extended periods.
- Rechargeable: Ensures long-term usability without recurring costs, aligning with budget constraints and power generation components can be added in future phases e.g. Solar Power.
- Compatibility: Matches power requirements of the TTGO T-Beam and Components.

4. LoRa Communication Module (Integrated with TTGO T-Beam)

- Integrated Communication: LoRa module is built into TTGO T-Beam.
- Long-Range Capability: Ideal for transmitting data over long distances, crucial for field-based monitoring with distances up to 15km and beyond supported at the expense of power (transmission power).

5. GPS Module (Integrated with TTGO T-Beam)

- Time Synchronization: Provides accurate time-stamped data for monitoring soil moisture trends and synchronising real time clock (RTC) across different devices for duty cycles, sleep cycles and data transmission.
- Power Efficiency: GPS module is activated only when needed.

System Type | Component Type | Component Make and Model | No. of Components | Total Cost | Voltage | Current | Libraries | Relevant Links
Soil Moisture IoT Prototype and LoRa Gateway | Board Microcontroller, WiFi | TTGO T-Beam v1.1 (https://www.lilygo.cc/products/t-beam-v1-1-esp32-lora-module) | 2 | Available at UWA | See AXP192 datasheet for input and output ranges | See AXP192 datasheet for input and output ranges | LilyGo Github (https://github.com/Xinyuan-LilyGO/LilyGo-LoRa-Series/blob/master/assets/image/t-beam_v1.1_pinmap.jpg)– LoRa Sender Receiver code TinyGPS (https://www.arduino.cc/reference/en/libraries/tinygps/) – GPS Module | 1. Pin Diagram (https://github.com/Xinyuan-LilyGO/LilyGo-LoRa-Series/blob/master/assets/image/t-beam_v1.1_pinmap.jpg) 2. Deep Sleep (https://www.reddit.com/r/esp32/comments/movnp3/comment/hlad7wh/) 3. Firmware (https://meshtastic.org/docs/hardware/devices/tbeam/?t-beam=1.1) 4. Transmission Power (https://tinymicros.com/wiki/TTGO_T-Beam)
Soil Moisture IoT Prototype and LoRa Gateway | Battery | 18650 Samsung INR18650-30Q Battery (https://www.alldatasheet.com/datasheet-pdf/view/1131828/SAMSUNG/INR18650-30Q.html) | 2 | Available at UWA | Nominal Voltage: 3.6V | Battery Capacity: 3000mAh | Arduino Low Power (https://www.arduino.cc/reference/en/libraries/arduino-low-power/lowpower.deepsleep/) – For Deep Sleep | N/A
Soil Moisture IoT Prototype and LoRa Gateway | Power Management Unit | AXP192 (https://www.alldatasheet.com/datasheet-pdf/pdf/1134496/XPOWER/AXP192.html) (Part of TTGO T-Beam) | 2 | Available at UWA | Input Voltage: 2.9V – 6.3V Output Voltage: 3.3V – 5V | Maximum 1.2A at 3.3V | LilyGo PMU (https://github.com/Xinyuan-LilyGO/LilyGo-LoRa-Series/tree/master/examples/PMU) – Example PMU code | N/A
Soil Moisture IoT Prototype | Prototyping Wires (F/M) | Jumper Wire 20cm Ribbon (F/F, 40pcs) (https://core-electronics.com.au/solderless-breadboard-jumper-cable-wires-female-female-40-pieces.html) | 1 pack | Available at UWA | N/A | N/A | N/A | N/A
Soil Moisture IoT Prototype | Prototyping Wires (M/M) | Jumper Wire 20cm Ribbon (M/F, 40pcs) (https://core-electronics.com.au/male-female-jumper-wire-40-20cm.html) | 1 pack | Available at UWA | N/A | N/A | N/A | N/A
Soil Moisture IoT Prototype | Prototyping Wires (M/M) | Jumper Wire 20cm Ribbon (M/M, 40pcs) (https://core-electronics.com.au/jumper-wire-20cm-ribbon-of-40pcs.html) | 1 pack | Available at UWA | N/A | N/A | N/A | N/A
Soil Moisture IoT Prototype | Breadboard | Solderless Breadboard | 1 | Available at UWA | N/A | N/A | N/A | N/A
Soil Moisture IoT Prototype | Soil Moisture Sensor | Capacitive Soil Moisture Sensor (v2.0) (https://core-electronics.com.au/capacitive-soil-moisture-sensor-v20.html) | 3 | Equivalent available at UWA | Operating Voltage: 3.3V - 5.0V | Current Consumption: 5.68mA | Testing and Calibration (https://tutorials.probots.co.in/using-soil-moisture-sensor-capacitive-v2-0-module-for-arduino/) – Example Arduino Code | 1. Connecting to ADC (https://youtu.be/pFQaFnqpOtQ?si=VTVHsh_XowTvk_oX&t=204) 2. Connecting to Arduino UNO (https://arduino-tutorials.net/tutorial/capacitive-soil-moisture-sensor-arduino)

Components List

This is a comprehensive list of components we require to create an MVP prototype that can be used to demonstrate the Soil Moisture Monitoring System and Communication to the LoRa gateway before the data is transmitted to AWS IoT Core over the Internet using MQTT protocol.

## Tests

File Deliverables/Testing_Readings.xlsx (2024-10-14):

Time_Duration | Sensor_BoardID(Constant) | Date | Time | Latitude | Longitude | Battery | Depth1 | Moisture_Percentage1 | Depth2 | Moisture_Percentage2 | Depth3 | Moisture_Percentage3 | Packet_Index | Gateway_ID | Storing_Latitude | Storing_Longitude | Storing_time | RSSI | SNR | Packet_Size
2 mins | sb1 | 2024-10-04 | 15:46:56 | -31.980473 | 115.8172 | 99% | 10 | 100 | 20 | 100 | 30 | 100 | 2 | gt1 | -31.979454 | 115.818483 | 15:46:50 | -91 | 1 | 72
1 min | sb1 | 2024-10-04 | 15:48:03 | -31.980473 | 115.8172 | 99% | 10 | 100 | 20 | 100 | 30 | 100 | 3 | gt1 | -31.979454 | 115.818483 | 15:47:56 | -89 | 7.75 | 72
1 min | sb1 | 2024-10-04 | 15:49:10 | -31.980473 | 115.8172 | 99% | 10 | 100 | 20 | 100 | 30 | 100 | 4 | gt1 | -31.979496 | 115.818405 | 15:49:02 | -96 | 5 | 72
1 min | sb1 | 2024-10-04 | 15:50:16 | -31.980473 | 115.8172 | 99% | 10 | 100 | 20 | 100 | 30 | 100 | 5 | gt1 | -31.979485 | 115.818425 | 15:50:07 | -95 | 7 | 72
1 min | sb1 | 2024-10-04 | 15:51:23 | -31.980473 | 115.8172 | 99% | 10 | 100 | 20 | 100 | 30 | 100 | 6 | gt1 | -31.979503 | 115.818417 | 15:51:12 | -91 | -0.25 | 72
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

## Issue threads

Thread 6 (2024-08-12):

Stakeholder Questions and Answers - Farmer

asadmaza, 2024-08-12:
We need to get some information from an actual farmer to find out any issues we may face later on in the project early on.
This should help us consider any challenges or considerations for practical implementation at a later stage. May also prime stakeholder to consider what this means for their current processes.

asadmaza, 2024-08-12:
Created a list of questions, pushed to repository.
See: https://github.com/bellabaohaha/CITS5206-Gp2/commit/902df55096b4f0ddbd34ee9ea7031349d1a167f9

Sending clients email to ask Stakeholder or check whether questions are appropriate.

Will update this when they reply

asadmaza, 2024-08-23:
I'm not sure if we need this right now as Gustavo hasn't mentioned if its required. If we need to get specific feedback I'm sure we can at some stage in the future.

Closing

Closed 2024-08-23.

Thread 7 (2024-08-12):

John Deere API Developer Access

asadmaza, 2024-08-12:
Received partial access to some APIs but the API we need access to is Assets and it was declined.
The ticket was closed over the weekend.
Have requested access to Assets and Notifications again and will have to provide a business use case.

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

asadmaza, 2024-08-15:
Forgot to screenshot support team reply

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

asadmaza, 2024-08-15:
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

Ticket closed again...

asadmaza, 2024-08-21:
Gustavo sent a few emails to support team at John Deere to get access on the UWA Solutions account, although approved the access is not shown in the API portal.

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

Requested again:

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

asadmaza, 2024-08-23:
Gustavo managed to get us access yesterday. Closing ticket.

Closed 2024-08-23.

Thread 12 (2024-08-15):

System Design - Solution Architecture

asadmaza, 2024-08-15:
Need to provide a first draft of the requirements for the ideal solution.

We will be focusing on a subset of the ideal solution as the scope of the project is quite large to get an MVP

asadmaza, 2024-08-15:
Using Draw.IO

Identified following information needs to be collected:

1. Soil Moisture % at varying depths - for farmer's decision making purposes to operate heavy machinery
2. TimeDate - for logging purposes and farmer can make timely decisions
3. System ID - Unique ID to keep a track of the IoT system
4. Paddock ID - need to confirm with stakeholders whether this is required or it can be handled over JD Platform?
5. GPS Location - for tracking system location
6. **Optional:** Manual Sensor Reading - Not sure if this can be done as we are integrating into John Deere and there might be a limitation here. Also will be at the cost of power because most microcontroller boards don't have the ability to wake up on command. This would have to be somehow manually checked every hour or so, hence at the cost of power. To confirm with stakeholders?

Frequency of data collection and transmission:
Twice daily 4AM and 12PM - to be confirmed?

asadmaza, 2024-08-15:
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

Added to Deliverables Folder. See [68bf5c4](https://github.com/bellabaohaha/CITS5206-Gp2/commit/68bf5c47283950aebb8ab018116698d9b325c725)

asadmaza, 2024-08-21:
On the back off our meeting last Friday I'm reopening this to design the solution again.

asadmaza, 2024-08-21:
Idea for system architecture we will have for the client:

1. IoT System composed of 3 soil moisture % to represent (fake) 3 different depths and soil moisture levels. 1 board (T-Beam) and battery. We need to have a duty cycle and a sleep cycle that will take two sets of soil moisture readings, one at 4am and another at 12pm and send IoT System ID, soil moisture at depths and the TimeDate of the reading and the GPS location to the Gateway, when it doesn't take a reading it should be in power saving/sleep mode. The IoT system will communicate this information to the T-Beam Gateway using LoRa protocol. The time is synced with GPS (TinyGPS) that is embedded as part of T-Beam.

2. T-Beam Gateway - will wake up at the same time and will take the information from the IoT system through LoRa protocol and communicate Gateway to Internet. This gateway will then add an attribute to the JSON of TimeDate sent to database from this gateway and the Gateway ID and send the information to AWS IoT Core using the internet, probably MQTT.

3. AWS ecosystem - once in AWS IoT core the information sent which is the GPS location, TimeDate of Reading, TimeDate of data sent to database and will communicate this to DynamoDB to save the data.
4. From DynamoDB the data needs to go in two directions, one to AWS quicksights with a dashboard to display the soil moisture reading data at 4am and then at 12pm so near real time. (trigger the action if its not automatic). We need to design this at some stage further to show what types of insights we can use with this data.

5. Optional step (depends on time to get API access as Gustavo is still trying to get access) from DynamoDB the data could be sent to John Deere API using OAuth somehow, however this will strip the GatewayID and Datetime sent to database and just send the IoT Soil Moisture data at 3 different fake depths.

asadmaza, 2024-08-21:
Going to start on building the diagram

asadmaza, 2024-08-21:
Ok completed System Diagram, added in AWS Lambda, documents show, we can use an event driven Function that can send the data to John Deere API in the future if required. Also highly scalable and works well because its serverless.

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

asadmaza, 2024-08-21:
See [902d532](https://github.com/bellabaohaha/CITS5206-Gp2/commit/902d532957de3d9c969d7144f230f0014d2657cd)

Closed 2024-08-21.

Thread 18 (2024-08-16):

STRIDE Analysis

asadmaza, 2024-08-16:
Conducting STRIDE analysis on the UML DFD Diagram for the Ideal Solution

asadmaza, 2024-08-16:
Realised issue with DFD, Gateway is a Node, not really on the Cloud.

Updated. See Create Components, DFD and Class UML Diagrams for System
[#13](https://github.com/bellabaohaha/CITS5206-Gp2/issues/13) for Old diagram

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

asadmaza, 2024-08-16:
Forgot to upload my STRIDE from earlier. Client has changed scope so this will be redundant...

| **STRIDE Category**     | **Threat**                                                                                                                                             | **Impact**                                                                                                                 | **Risk Level** | **Mitigation Strategy**                                                                                                                                                       | **When to Address**               |
|-------------------------|--------------------------------------------------------------------------------------------------------------------------------------------------------|----------------------------------------------------------------------------------------------------------------------------|----------------|-------------------------------------------------------------------------------------------------------------------------------------------------------------------------------|-----------------------------------|
| **Spoofing**            | An attacker could spoof the identity of the farmer or the John Deere Platform login interface, tricking the farmer into providing login credentials.    | Unauthorized access to the John Deere Platform could lead to control over the IoT system and sensitive data.               | High           | **Mitigate** - Ask the farmer to enable Multi-Factor Authentication (MFA) for added security.                                                                                 | **Feasibility/PoC Stage**         |
| **Tampering**           | An attacker could physically access the IoT devices and tamper with the data before it is sent to the cloud.                                            | Altered sensor readings could result in incorrect soil moisture data, leading to poor crop management.                     | Medium         | **Mitigate** - Use tamper-evident enclosures for physical devices and employ data integrity checks to detect unauthorized modifications.                                       | **MVP Stage**                     |
| **Repudiation**         | A farmer or attacker could deny having sent specific commands or accessed certain data within the John Deere Platform.                                  | Lack of accountability could complicate troubleshooting and auditing.                                                      | Low            | **Mitigate** - Ensure comprehensive logging and require user consent for actions.                                                                                              | **MVP Stage**                     |
| **Information Disclosure** | Sensitive information could be leaked during transmission between IoT systems, Internet Gateway, Cloud Provider, or John Deere Platform.               | Disclosure of sensitive data could lead to privacy violations and competitive disadvantages.                               | High           | **Mitigate** - Use OAuth 2.0 to prevent MITM attacks, and employ strong encryption protocols (e.g., TLS) for secure data transmission.                                        | **Feasibility/PoC Stage**         |
| **Denial of Service (DoS)** | An attacker could flood the Internet Gateway or LoRa communication channel with excessive traffic, disrupting the flow of data.                        | Disruption could prevent real-time soil moisture data collection, leading to delayed or incorrect farming decisions.       | Medium         | **Transfer** - Employ a third-party DDoS protection service.                                                                                                                    | **Product Ready for Deployment**  |
| **Elevation of Privilege** | An attacker could exploit a vulnerability in the John Deere Platform to gain unauthorized administrative privileges.                                   | Disruption of operations or access to sensitive data.                                                                      | Low            | **Mitigate** - Apply strict access control, regularly patch vulnerabilities, and enforce the principle of least privilege.                                                     | **Feasibility/PoC Stage**         |

asadmaza, 2024-08-21:
Closing, completed STRIDE analysis. See: [3ac4da3](https://github.com/bellabaohaha/CITS5206-Gp2/commit/3ac4da32644ec84977e81dcf9c67e24c59bdb429)

Closed 2024-08-21.

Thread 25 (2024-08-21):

Mock Prototype Dashboard

asadmaza, 2024-08-21:
Creating task for Mock Protoype dashboard

asadmaza, 2024-08-21:
Next Steps:

Create Code for generating mock data for Mock Dashboard

asadmaza, 2024-08-21:
Created code, ran it to generate mock data over a year.

Next Steps:
Ingest data into PowerBI and show what the dashboard might look like.

asadmaza, 2024-08-21:
Ok so I've completed the mock dashboard

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

Publishing and sending to Atif and Gustavo in an email so they can check before our meeting on Friday.

Closed 2024-08-21.

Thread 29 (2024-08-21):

Gantt Chart

asadmaza, 2024-08-21:

asadmaza, 2024-08-21:
I've finalised everything but the Gantt chart, going to do this now...

asadmaza, 2024-08-21:
Will use Github Issues.

asadmaza, 2024-08-21:
Designing it based on time remaining after this week's submission and team members aren't available in study break.

**Project Timeframe:**

Start Date: Monday, 26/08/2024
Skip Study Break Week: 02/09/2024
End Date: Friday, 18/10/2024 (including a buffer week)
Total Duration: 8 weeks (excluding study break)

**Gantt Chart Timeline**

Week 1: Planning and Initial Setup (26/08/2024 - 30/08/2024)
Week 2-3: Prototype Development (09/09/2024 - 20/09/2024)
Week 4-5: Gateway and Cloud Integration (23/09/2024 - 04/10/2024)
Week 6: Visualization & Analytics (07/10/2024 - 11/10/2024)
Week 7-8: Testing, Documentation, and Buffer (14/10/2024 - 18/10/2024)

**Key Stages and Tasks**

Stage 1: Planning & Initial Setup (Week 1)

Task 1: Finalize Project Documentation Plan
Assigned to: David Shang
Duration: 26/08/2024 - 30/08/2024
Objective: Develop a structure for the project documentation, including sections and subsections, and get feedback from the client.
Friday Meeting: Feedback session with stakeholders.

Task 2:  Component Procurement
Assigned to: Bella Bao
Duration: 26/08/2024 - 30/08/2024
Objective: Get components for the IoT prototype and gateway system, consult Atif/Andrew Burrell.

Stage 2: Prototype Development (Week 2-3)

Task 3: Soil Moisture Sensor Integration
Assigned to: Dharani Kumari Nagali
Duration: 09/09/2024 - 13/09/2024
Objective: Integrate the soil moisture sensors with the TTGO T-Beam microcontroller, test, and calibrate.

Task 4: Power Management System
Assigned to: Udaymithra Kalla
Duration: 09/09/2024 - 13/09/2024
Objective: Develop and test a power management system for the IoT prototype, focusing on sleep and duty cycles.

Task 5: LoRa Communication Setup
Assigned to: Hanni Bao
Duration: 09/09/2024 - 20/09/2024
Objective: Set up and test the LoRa communication between the Soil Moisture Monitoring System and the LoRa Gateway.

Stage 3: Gateway and Cloud Integration (Week 4-5)

Task 6: Gateway Communication and Data Transmission
Assigned to: David Shang
Duration: 23/09/2024 - 27/09/2024
Objective: Configure the LoRa gateway to receive data from the IoT prototype and transmit it to AWS IoT Core.

Task 7: Cloud Storage Setup (AWS IoT Core & DynamoDB)
Assigned to: Asad Maza
Duration: 30/09/2024 - 04/10/2024
Objective: Set up AWS IoT Core and DynamoDB to store the transmitted data from the gateway.

Stage 4: Visualization & Analytics (Week 6)

Task 8: Develop Visualization Dashboard (Alternative 1) OR Connect to John Deere API
Assigned to: Bella Bao & Dharani Kumari Nagali
Duration: 07/10/2024 - 11/10/2024
Objective: Create basic visualization dashboard using AWS QuickSight or send data to John Deere Platform using Assets API.

Stage 5: Testing, Documentation, and Buffer (Week 7-8)

Task 9: System Testing and Validation
Assigned to: Udaymithra Kalla & Hanni Bao
Duration: 14/10/2024 - 16/10/2024
Objective: Conduct end-to-end testing of the system, validate data transmission, and refine any issues found.

Task 10: Finalize Project Documentation
Assigned to: Asad Maza & David Shang
Duration: 14/10/2024 - 17/10/2024
Objective: Complete the project documentation, including final reports, and prepare for the handover.

Task 11: Stakeholder Presentation and Handover
Assigned to: All Members
Duration: 18/10/2024
Objective: Present the final solution to stakeholders and complete the handover.

asadmaza, 2024-08-21:
Asked team to create the Gantt Chart. Closing.

Closed 2024-08-21.

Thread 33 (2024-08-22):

Component Procurement

David-Shang, 2024-08-22:
Get components for the IoT prototype and gateway system, consult Atif/Andrew Burrell.

asadmaza, 2024-08-23:
Off the back of our meeting with Atif and Gustavo

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

We may not need to get the components but identification will be important I imagine.

bellabaohaha, 2024-08-28:
- I did some research and I found some device that provides multiple depth monitor. (https://hydroterra.com.au/product/sentek-enviroscan-soil-moisture-probe/ ) However this device seems expensive. The sensor node should be lightweight, power-efficient, and low-cost. For cost efficiency I suggest we use the current ones and manually insert into different depth.

- Dr. Omar suggested to use a proper solar panel for the power. However the implementation of solar panel depends on farm so I suggest we go with safety choice battery.
- As Dr. Omar mentioned, GPS modules are power-intensive, so it's better to record the sensor location at deployment rather than using a dedicated GPS module continuously. I deleted the GPS module required in our original list. Instead we will manually record the coordinate.
- If below components are fine, we can email client and get the component this Friday.
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

asadmaza, 2024-08-28:
GPS module is inbuilt in the TTGO T-Beam.

I think a better solution than deleting it would be to:

Have a deployment set of code where the GPS location is received on initial setup.

Another set of code that gets sensor readings and puts board to sleep.

Very similar to initial Setup and void infinite loops as you have in most IoT programs.

That way we only get location once instead.

asadmaza, 2024-08-28:
See these links about turning off GPS on T-Beam to save power after getting it once and only once on deployment:

https://meshtastic.org/docs/hardware/devices/tbeam/buttons/ - Hardware method

https://github.com/LilyGO/TTGO-T-Beam/issues/19 - SDK/Programmatic method

bellabaohaha, 2024-08-30:
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

asadmaza, 2024-09-04:
FYI I gathered and gave the components to the team yesterday and have emailed Andy.

Please go through the sensors that Gustavo has sent via email.

I spoke with Atif yesterday and he also recommended this paper:
https://www.researchgate.net/publication/372604305_Evaluation_of_Three_Soil_Moisture_Profile_Sensors_Using_Laboratory_and_Field_Experiments

See what works with our constraints, just had a quick look at your constraints, some feedback: we don't need to power it via the TTGO (5V/3.3V), it could have its own power delivery, as long as we can communicate with the TTGO.

bellabaohaha, 2024-09-20:
Summary of the sensors video sent by client Gustavo:

There are many types of moisture sensors in the market to choose from. In the video, the speaker Troy Peters provides an overview of various soil moisture sensors used in agriculture, focusing on their operational mechanisms and suitability for irrigation management. The neutron probe is considered the gold standard for measuring soil moisture. It works by emitting neutrons from a radioactive source, which interact with hydrogen atoms in the soil to give an accurate reading of water content. Despite its accuracy and ability to sample large areas, neutron probes are costly, involve radioactive materials, and require manual handling, which limits their widespread use among farmers.

The tensiometer measures soil water tension, which is the force plants need to exert to extract water from the soil. This tool is affordable and easy to use, providing a direct indication of when irrigation is needed. However, it only measures a small area and does not provide information on how much water to apply. The sensor is less suitable for determining precise water volumes but can be very helpful in monitoring when plants begin to experience water stress.

Resistance sensors, widely used due to their affordability, measure soil moisture by detecting electrical resistance between conductors in a gypsum block. These sensors provide trends in soil water potential, which can be useful for irrigation scheduling. However, they can degrade over time and are affected by salinity and soil structure, making them less reliable in certain conditions. Their low power consumption and ability to log data continuously make them popular for longer-term field use.

The capacitance sensor measures soil’s ability to hold an electric charge between two conductors, giving an estimate of the soil water content. These sensors are sensitive to installation and soil structure, but they offer ease of use through data logging and automation. They are particularly effective in sandy soils, though they can be influenced by soil salinity and temperature.

Another technology, time domain reflectometry (TDR), works by sending an electric pulse to measure the soil’s dielectric properties. It provides a broader measurement area and is less sensitive to soil inconsistencies than capacitance sensors, though it requires more sophisticated electronics and energy to operate.

Closed 2024-09-29.

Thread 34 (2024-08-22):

Soil Moisture Sensor Integration

David-Shang, 2024-08-22:
Integrate the soil moisture sensors with the TTGO T-Beam microcontroller, test, and calibrate.

dharaninagala, 2024-09-18:
# Soil Moisture Monitoring with TTGO T-Beam - Completed

The integration of the soil moisture sensors with the TTGO T-Beam is successfully completed. All components are working as expected, with accurate sensor readings and stable LoRa communication. Calibration of the sensor for dry and wet conditions has been performed, and the firmware is working fine. Testing across different soil conditions shows consistent results, and the system is ready for deployment. Future enhancements can be implemented as needed.

dharaninagala, 2024-10-13:
**Measuring Soil Moisture Readings:**

Soil moisture levels at depths of 10 cm, 20 cm, and 30 cm can be measured using capacitive sensors connected to the TTGO T-Beam. Each sensor is accessed by the following pins: Pin 14 (10 cm), Pin 13 (20 cm), and Pin 15 (30 cm). The analogRead() function reads unprocessed sensor readings, thereafter transformed into moisture percentages via the map() function. The mapping converts measurements to a scale ranging from 0% (dry) to 100% (wet), by using established wet and dry reference values. The results are presented in a readable format and displayed with a 3-second interval between readings for stability.

Code snippet:

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

**Error Correction:**

The sensor which we are using in this project is of basic version and not that accurate, sometimes it gives a weird readings when measured in different conditions and if that values are used to calculate the percentage of soil moisture, the percentage would not be in proper format.So to take that outlier values out of consideration,  if any sensor reading is less or greater than of constant wet/dry values, that difference of the value should be added or removed to make that sensor value comes under acceptable range which then gives us correct moisture percentage reading.

**Error Correction Logic:**
The sensors might give readings that aren't in the calibrated range due to incorrect moisture percentage readings or to environmental factors. To fix these outliers:
Each sensor reading is compared to the calibrated wet and dry constants in the code once the sensor readings are read from the analogue pins.
**For Lower bound check:**
• If the sensorReading is less than the constant wet value (which represents the minimum calibrated value), it is set equal to wet.
**For Upper bound check:**
• If the sensorReading is greater than the constant dry value (which represents the maximum calibrated value), it is set equal to dry.

Code snippet:
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

Output:
When the updated code is uploaded to the system and tested under both wet and dry conditions, the implemented error correction logic effectively excludes outlier values from the sensor readings. This ensures that the soil moisture readings and the calculated moisture percentages remain within acceptable ranges, providing accurate and reliable measurements.

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

dharaninagala, 2024-10-17:
Calibration Steps:

1. Preparation of Dry Soil Sample
Step 1: Used a glass container with dry loam soil. Ensured the soil is completely dry and free from moisture.
Step 2: Labelled the sensors as Sensor 1, Sensor 2, and Sensor 3 for identification.

2. Dry Condition Calibration
 For Each Sensor (Repeat Steps Below for Sensors 1, 2, and 3):
a. Inserted the sensor into the dry soil at the first position.
• Recorded the reading as DryValue1.
b. Removed and wiped the sensor with a piece of cloth and reinserted the sensor into a different position in the soil.
• Recorded the reading as DryValue2.
c. Repeated once more for a third position.
• Recorded the reading as DryValue3.
d. Calculated the average of DryValue1, DryValue2, and DryValue3.
• This average is the Dry Value for that sensor.

3. Preparation of Wet Soil Sample
Step 1: Measured 100ml of water using the measuring cup.
Step 2: Poured the water evenly into the loam soil in the glass container.
Step 3: Mixed the soil thoroughly to ensure uniform moisture throughout.

4. Wet Condition Calibration
For Each Sensor (Repeat Steps Below for Sensors 1, 2, and 3):
a. Inserted the sensor into the wet soil at the first position.
•Recorded the reading as WetValue1.
b. Remove and wipe the sensor with a piece of cloth and reinsert the sensor into a different position in the wet soil.
•Recorded the reading as WetValue2.
c. Repeated once more for a third position.
•Recorded the reading as WetValue3.
d. Calculated the average of WetValue1, WetValue2, and WetValue3.
• This average is the Wet Value for that sensor.

5. Recording Calibration Data
Step 1: Organized all recorded values in a spreadsheet or table for clarity.
Step 2: Documented the Average Dry Value and Average Wet Value for each sensor.
Step 3: These values will serve as reference points in the code's map() function to convert raw readings into percentage moisture levels.

Closed 2024-10-17.

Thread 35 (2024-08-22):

Power Management System

David-Shang, 2024-08-22:
Develop and test a power management system for the IoT prototype, focusing on sleep and duty cycles.

asadmaza, 2024-08-28:
See these links about turning off GPS on T-Beam to save power after getting it once and only once on deployment:

https://meshtastic.org/docs/hardware/devices/tbeam/buttons/ - Hardware method

https://github.com/LilyGO/TTGO-T-Beam/issues/19 - SDK/Programmatic method

udaymithra, 2024-10-11:
For the project code to work, following libraries with respective versions needs to be installed in the Arduino IDE.
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

In the project source code, following configuration files  and libraries need to placed at the top.

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

For setting up and optimizing the LoRa communication module, radio configuration parameters needs to be set with following values.

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

For GPS and Serial communication, I created a gps and Serial1 objects

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

Initialised the External LED bulb to GPIO 25 and a manual button is GPIO 38 to turn off/ turn on  gps location

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

Variables to track gps state, button state, no of times button pressed and boolean variable to know whether gps data received.
RTC_DATA_ATTR is used to retain the values during deep sleep.
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

an array is initialised to store the gps data values and a boolean variable to know the time is synced with RTC.

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

Variables used for soil moisture readings and sensors connected to GPIO pins 13,14,15. and also defined constant values which are calibrated for dry and wet conditions.

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

A constant scheduledTimes array is defined which contains the time for which the system needs to wake from deep sleep.

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

**Setup() function:**
It is used to initialize LoRa and handles the system when wake up from deep sleep.
If the device woke up from deep sleep, it initializes peripherals for readings, checks if it's a scheduled time, takes readings if necessary, and then goes back to sleep.
Along with this it handles if the system is reset / power off and power on it initializes all peripherals and turns on the GPS module.

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

**loop() function:**
It handles following:
**GPS Data Acquisition**: If GPS is on and data hasn't been received yet, it reads and processes GPS data.
**Deep Sleep Entry**: Once GPS is off and data is received, it calculates sleep time until the next scheduled reading and enters deep sleep.
**Battery Status Monitoring**: Continuously updates battery percentage.

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

**handleButtonPress() function features:**

**Button Debouncing and Press Counting**: Implements debouncing logic and counts presses to toggle GPS.
**GPS Control**: Functions to turn GPS on or off and control the LED indicator.

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

**storeGPSData and printGPSData function features:**
**Data Storage:** Stores latitude, longitude, battery percentage, time, and date.
**Data Printing:** Prints GPS data to the Serial Monitor.

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

**syncTimeWithRTC() function features:**
Synchronizes the ESP32's internal RTC with GPS time which is adjusted for AWST (UTC+8).

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

**checkBatteryStatus() function** is used to check whether battery is inserted into the board or not.

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

**initPeripheralsForReadings() function** sets up pins for soil moisture sensors.

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

**takeSoilMoistureReadings() function** reads analog values, constrains them, maps to percentage, and prints them to serial monitor.

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

**createAndPrintPayload() function:**

This function is used to gathers all sensor data and formats it into a comma-separated string.In the payload it also sends a unique packet index which defines the packet number for each packet it sends to gateway.It's value is incremented by 1 each time at the end after the payload is sent.

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

**isScheduledTime() function** determines if it's time to take a reading or not

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

**getTimeUntilNextScheduledReading() function** calculates how long the device should sleep until the next scheduled reading or time synchronization.

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

**initializeLoRa() function** is used to configures LoRa parameters and initializes communication

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

Closed 2024-10-11.

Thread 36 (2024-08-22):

LoRa Communication Setup

David-Shang, 2024-08-22:
Set up and test the LoRa communication between the Soil Moisture Monitoring System and the LoRa Gateway.

asadmaza, 2024-09-04:
Hey @ITwoaini  Hanni,

To clarify, your task here is to setup the LoRa communication between the soil moisture monitoring node and the Internet/LoRa Gateway (TTGO). You will have to work with Uday/Dharani on this one to ensure they have their sender setup and you have your receiver setup (see LilyGo library that I linked under components list I created).

I imagine it will be pretty straight forward to send from their TTGO (Soil Moisture Node) to yours (setup as LoRa Receiver). Once you achieve that, I would then work with David as he's responsible for Data transmission to AWS IoT Core. If you have any confusion, it's best you come in to uni tomorrow (05/09) as I will be available to guide you all towards a viable solution.

What I explained about the internet gateway and adding the metadata as per the dataflow diagram and connecting and transmitting the data to IoT Core is actually David's task - please check/remind him when he's available. @David-Shang

ITwoaini, 2024-09-04:
Hey Asad, thanks for the explanation. I'll come to the university tomorrow (05/09) to discuss.

ITwoaini, 2024-10-18:
Communication setup:

We followed Australia’s frequency regulations, configuring the system to use a 915 MHz frequency, a 125 kHz signal bandwidth, and a spreading factor of 10. While these parameters are theoretically expected to provide a good balance between energy efficiency and communication range, initial tests indicated that the system did not perform optimally. Even at distances less than 100 meters, we experienced communication issues, suggesting that further optimization is necessary for reliable operation in large-scale agricultural scenarios. While these parameters are not exhaustive, they represent the key settings optimized for our project. Further tuning of additional parameters can further improve communication reliability. We also use a sync word of 0xAB to ensure the sensor board and gateway communicate properly, while avoiding interference from other LoRa networks.

ITwoaini, 2024-10-18:
**Test data and analysis for communication:**

We conducted a brief test in a controlled indoor laboratory environment to verify whether the LoRa communication between the sensor board and the gateway was functioning properly. Using two TTGO T-Beam development boards—one as the sender and the other as the receiver—the sender transmitted data packets every 2 seconds containing three simulated soil moisture sensor readings (values: 123, 321, 456).

The receiver continuously monitored the LoRa channel. While the receiver successfully received most of the transmitted data packets, we observed some data corruption and packet loss. Out of 20 data packets sent, 16 were correctly received, resulting in a packet loss rate of 20%.

_Below table shows the first ten rows of Test Results of Lab Testing_

Packet No.  Mock Sensor Data	RSSI (dBm)	SNR (dB)
1	[123,321,456]	                         -21	                 10.00
2	[123,321,456]	                         -21	                 10.50
3	[123,321,456]	                         -21	                 10.25
4	[123,321,456]	                         -21	                 10.25
5	[123,321,456]	                         -21	                 10.25
6	[123,321,456]	                         -21	                  9.75
7	[Data Corrupted]	                 -21	                  —
8	[123,321,456]	                         -21	                 10.25
9	[123,321,456]	                         -21	                 10.25
10	[Data Corrupted]	                 -21	                  —

The RSSI values remained stable at around -21 dBm, and the SNR values ranged from 9.75 dB to 10.50 dB. According to Semtech's guidelines, reliable communication typically requires RSSI values higher than -120 dBm and SNR values above 0 dB. Our observed values fall well within these ideal ranges, indicating good signal strength and quality in the laboratory environment at short range.

Despite the ideal RSSI and SNR values, we encountered instances of packet loss and data corruption. This suggests that factors other than signal strength and quality are affecting communication reliability. Given the controlled environment, potential causes may include interference from nearby wireless devices (such as Wi-Fi networks) or timing issues in the LoRa protocol. Additionally, the lack of an acknowledgment mechanism in our current communication setup may have contributed to data loss, as there is no retransmission when packets are corrupted or lost.

Closed 2024-10-09.

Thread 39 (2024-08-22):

Develop Visualization Dashboard (Priority 1)

David-Shang, 2024-08-22:
Priority 1: Create a basic visualization dashboard using AWS QuickSight.

Priority 2: Send data to the John Deere Platform using Assets API.

bellabaohaha, 2024-09-11:
What to contain in the QuickSight interface:

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

bellabaohaha, 2024-09-19:
Received feedback from client stating it is good.
I added our UWA logo and battery level as well.
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

bellabaohaha, 2024-10-10:
- Update AWS DynamoDB for latest dataset
- Update dashboard:
1. Only show battery visual when battery <20%:
 ifelse(
{sensor_board_battery_percentage} >20 ,"Battery good",
{sensor_board_battery_percentage}<=20, "Battery low only {sensor_board_battery_percentage}",
"no data"
)
2. Add a card to show message under different conditions: moisture level >40 and <=40
3. Update the gauge chart to show icon and change color under different moisture level
4. Add a table for testing data(to be updated once testing data finalized to dynamoDB)

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

bellabaohaha, 2024-10-17:
**Step 1 Visualization Selection**
Various types of visuals are selected to present the report for best effects. A gauge chart is selected to display soil moisture level in a simple and intuitive format. It effectively displays real-time status information, such as whether the soil moisture is within the desired range, enabling users to quickly assess current conditions.

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

A line chart is selected to display historical trends in soil moisture. The x axis is a sensor timestamp by ascending order. It shows four lines indicating moisture levels of different depths and an average moisture level. It allows users to track changes over time and to help them make data-driven decisions about irrigation. The inclusion of threshold lines for the lowest acceptable moisture levels adds clarity, ensuring users can easily determine whether moisture levels are within ideal range.

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

Geospatial maps were included to visualize the locations of different sensor boards and gateways. This is particularly useful in understanding how moisture levels vary across different areas of the monitored field.

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

**Step 2 Adding Calculated Fields**
As the imported data is raw, calculated fields are created in the dashboard for visualisation, such as, average moisture level, battery warning, and moisture warning. The calculated fields are created using syntax of AWS QuickSight, for example, to get average moisture level we use below syntax:

({sensor_board_depth1_soil_moisture_percentage}+{sensor_board_depth2_soil_moisture_percentage}+{sensor_board_depth3_soil_moisture_percentage})/3

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

With this calculated field of average moisture level, we can apply this measure to a line chart to show the historical trend of average moisture level calculated from all the sensors of various depths.

We also added a calculated field for battery level to enable this show up only when the battery is less than 20%. Since the battery level does not fluctuate significantly over time, it doesn’t need to be displayed constantly.

ifelse(
{sensor_board_battery_percentage} >20, "Battery Good",
{sensor_board_battery_percentage}<=20, "Battery low only {sensor_board_battery_percentage}. Need to replace battery.",
NULL
)

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

**Step 3 Conditional Formatting**
To enhance the visualization for users to interpret, conditional formatting is implemented with different message, icons, and color of text. For example, the syntax for displaying different messages under different moisture level as below for the calculated field moisture_warning:

ifelse({average_moisture_level} >= 80, "Soil moisture is too high. Avoid farming operations until the water level subsides to prevent crop damage.",
{average_moisture_level}> 40 AND {average_moisture_level} < 80, "Soil moisture is optimal. No irrigation required.",
{average_moisture_level} <= 40, "Soil moisture is low. Irrigation needed. You can start watering and proceed with your farming tasks.",
"NULL"
)

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

It shows 3 different messages to indicate the aggregated moisture level is too wet, perfect, or too dry with different colors and icons. Here the threholds are set as 3: moisture level% >=80% as too wet, 40% < moisture level% < 80% as perfect, moisture level% <= 40% as too dry. The color of text and icon conditional formatting as below:

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

Here is how this visual would look like in different moisture level:

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

We implemented a card for battery information and applied conditional formatting, so it only appears a warning when the battery level drops below 20%. Other times, this card is hidden. It is in the left bottom in the dashboard.
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

 **Step 4 User-Customizable Features**
Each visual is edited with a title to make it more understandable. For the moisture level historical line chart, two reference lines are added to demonstrate the highest and lowest moisture level thresholds, which can be customized by users.

This dashboard also allows users to filter the data by sensors, gateways, and timestamp. For example, when a user would like to see the latest reading, they can filter by timestamp to keep the latest reading only. The filter can be applied to a single visual or the entire dashboard, and the visuals will be updated accordingly.

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
For example, here we select only the latest reading to filter and apply to the gauge chart. It would show this specific reading only. This provides users to get to know the data they need with convenience.

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

asadmaza, 2024-10-18:
Closing as work has been completed.

Closed 2024-10-18.

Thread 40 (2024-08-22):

System Testing and Validation

David-Shang, 2024-08-22:
Conduct end-to-end testing of the system, validate data transmission, and refine any issues found.

dharaninagala, 2024-10-18:
The following are the detailed steps for end to end testing performed :

**Overview**
The soil moisture monitoring system was tested on October 4th, 2024, between 3:30 PM and 4:00 PM at James Oval, University of Western Australia (UWA). The goal of the test was to assess the performance of the LoRa-based system in transmitting soil moisture data from three sensors embedded at different depths in the soil and monitor power consumption.

**Test Setup**
Moisture Sensors: Three sensors were placed at depths of 10 cm, 20 cm, and 30 cm to capture soil moisture content.

 **Test Procedure**
Initially, the sender and receiver were placed approximately 1 km apart, but no transmission data was received. It is likely that the buildings and the surrounding topology caused signal interference. To resolve this, the receiver was moved closer, with the sender placed on one side of the ground and the receiver on the opposite side. This adjustment allowed for successful transmission and data reception.

**Battery Monitoring**
During the test, the battery was monitored by unplugging the system to track battery drainage. The battery typically drained by 1% every 15 minutes, demonstrating efficient power consumption throughout the testing period.
The first transmission packet was missed, as seen from the test data. Data was successfully transmitted after the adjustment in receiver positioning, with consistent signal strength and data integrity observed in subsequent packets. The testing results table can be viewed in the following link https://github.com/bellabaohaha/CITS5206-Gp2/blob/main/Deliverables/Testing_Readings.xlsx

**Transmission Results**

The first transmission packet was missed, as seen from the test data. Data was successfully transmitted after the adjustment in receiver positioning, with consistent signal strength and data integrity observed in subsequent packets.

Once the data packets are received by the master gateway (receiver), additional information such as the gateway's position details (latitude and longitude), along with the signal strength indicators (RSSI and SNR) and packet size, are appended to the data. This enriched data is then transmitted to AWS IoT Core. Upon reaching the cloud platform, the data is stored in AWS DynamoDB for secure and scalable storage. The dashboard retrieves the data from DynamoDB and displays it on the screen, providing real-time insights and visualizations based on the collected information.

The soil moisture monitoring system successfully transmitted data over a shorter distance after resolving the initial transmission issue caused by the environment's topology. The system's energy efficiency was confirmed by minimal battery drain during the test, and soil moisture readings were consistent across all sensor depths. Future tests may include exploring different LoRa configurations or alternate locations to minimize packet loss over longer distances.

Closed 2024-10-18.

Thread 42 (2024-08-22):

Final Presentation and Handover

David-Shang, 2024-08-22:
Present the final solution to stakeholders and complete the handover.

asadmaza, 2024-10-10:
We had our draft presentation on Friday 04th October where client provided feedback on our soil moisture sensor system, internet gateway and dashboard. For details on the meeting and next steps please refer to Client Meetings.

asadmaza, 2024-10-18:
We had our second presentation on Friday 11th October at 10AM with Atif as Gustavo could not make it. We recorded it on teams however the recording was done in CSSE Lab 2.07 with the video conferencing teams software. I launched INC0894338 on UWA IT Service desk however they haven't responded.

Since then I have sent an email to Gustavo as per image below with all the details/summary of the meeting:
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

Adding in Hyper links from the email:
1. [API Docs for Historical Weather Data](https://open-meteo.com/en/docs/historical-forecast-api#hourly=temperature_2m,direct_radiation)
2. [Example of Detailed Github Project Task Steps](https://github.com/bellabaohaha/CITS5206-Gp2/issues/38)

I am going to create AWS read only accounts for Atif and Gustavo which I will then deprovision in a month in case they want to see how something is setup. I will send them an email today.

Closed 2024-10-18.

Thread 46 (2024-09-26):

AWS Data Pipeline to Quicksights

asadmaza, 2024-09-26:
### **Connecting DynamoDB Data to QuickSight via Athena**

As the data is now in DynamoDB, I need to get it from DynamoDB database to AWS Quicksights which is AWS proprietary business intelligence tool that allows data manipulation i.e. extract transform and load data and advanced visualisation capabilities.

As I've completed the transformation and ingestion of data into DynamoDB I'll also test end-to-end to ensure that the data is pushed to AWS Quicksights. I basically followed the tutorial [here](https://dev.to/aws-builders/finally-dynamodb-support-in-aws-quicksight-sort-of-2lbl) and the official AWS documentation [here](https://aws.amazon.com/blogs/big-data/visualize-amazon-dynamodb-insights-in-amazon-quicksight-using-the-amazon-athena-dynamodb-connector-and-aws-glue/.

In terms of architecture, it can appear quite complex but the main components I used were an AWS Glue Crawler, AWS S3 Spill Bucket, Athena's DynamoDB Connector with a Lambda Function. There were also quite a few AWS Policies that I had to create to get services to connect, however I will not dive into that level of detail for brevity. I'll explain in the main steps below what I used each of these components for and the queries I had to run to achieve the functionality required for the data to connect to AWS QuickSights. Finally, I conducted End-to-End Testing of the Data Pipeline by checking whether a message received by AWS IoT Core was transformed by my custom Lambda function and pushed into DynamoDB.

#### Step 1: Setup AWS Glue Crawler
-   Setup an **AWS Glue Crawler** to crawl my DynamoDB table for the JSON structure of items
- In the AWS Glue console, I created a new crawler, selected **DynamoDB** as data source, and pointed it to my **SoilMoistureData** table
- After manually running the crawler, I verified that the metadata for the table was successfully created in the AWS Glue Data Catalog. If there is a dynamic structure, I could schedule a Cron job to get the updated structure periodically

**Screenshot of Glue Crawler Setup**:
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

**Screenshot of Glue Crawler Provisioned**:
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

**Screenshot of Glue Crawler Output of JSON Structure**:
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

#### Step 2: Setup DynamoDB Athena Connector
- Setup **Athena DynamoDB Connector**
- I deployed the connector, setting the **SpillBucket** (an S3 bucket for large query results) and the **AthenaCatalogName**.
- After deployment, I verified that the Lambda function was created for the connector.

**Screenshot of S3 Spill Bucket Setup**:
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

**Screenshot of DynamoDB Connector Setup**:
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

**Screenshot of DynamoDB Connector Application (Lambda) Setup**:
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

**Screenshot of DynamoDB Connector Provisioned**:
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

#### Step 3: Create DynamoDB Table in Athena
- I opened **Athena Console** and navigated to **Query Editor**.
- I used **Data Source** connected to **DynamoDB Athena connector** and ran a query to check if the data was accessible:
  ```sql
  SELECT *
  FROM "dynamodb"."SoilMoistureData"
  LIMIT 10;
  ```
- The query successfully returned data from DynamoDB, confirming the connection was working.

**Screenshot of query returning results from DynamoDB**:
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

#### Step 4: Amazon QuickSight Configuration
- I navigated to **Amazon QuickSight** from AWS Management Console.
- On the **QuickSight home page**, I clicked **Manage Data** and selected **New Dataset** to create a new connection to Athena.
- I created a connection by giving the data source a name `DynamoDB` selected workgroup as `primary`.
- I then chose the database that the **Glue Crawler** created for my DynamoDB Table and selected `soilmoisturedata` table.
- I had a choice between connection modes of `direct query` or `SPICE`, direct query updates live so I decided to go for this instead of a manual refresh with SPLICE.

**Screenshot of Dataset Configuration**:
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

**Screenshot of Dataset Connection Mode**:
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

#### Step 5: IoT Core to Quicksights End-to-End Testing
- After the data loaded, I clicked **Visualize** and setup a table.
- I dragged and dropped fields `gateway_id`, `gateway_time` onto a bar chart to make sure it visualises.
- Then I sent the following message on `esp32/pub` in AWS IoT Core to test whether it would go from AWS IoT Core to DynamoDB and ultimately to the Quicksights Dashboard automatically. It worked perfectly as shown below.

**Screenshot of `gateway_id` and `gateway_time` showing only `gt1` gateway**:
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

**Screenshot of payload published to `esp32/pub` on IoT Core with `gt9999` for gateway**:
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

**Screenshot of payload with `gt99999` for gateway**:
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

**Screenshot showing payload delivered to Athena successfully when running SQL query**:
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

**Screenshot of table with both `gt1` and `gt99999`:
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

Now we need integration test from end to end, closing.

Closed 2024-09-26.

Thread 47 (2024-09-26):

Log of AWS Policies

asadmaza, 2024-09-26:
I used AWS IAM to manage the permissions and access for users and AWS services. There are numerous policies I crafted following the principle of least privelege to give enough access for users and AWS service to execute their role. Due to the numerous policies, it is ardious to actually go through each one. However, I think it's best to have a log of these policies so that we can troubleshoot or modify them accordingly when we are integration testing and finishing touches for the project. I will provide some examples of custom policies I've created for users, groups, and Roles.

**Screenshot of Example, policy created to deny access to Billing Console**:
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

**Screenshot of Example, policy created for AWS Quicksights Access**:
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

**Screenshot of Users in IAM that I onboarded to AWS**:
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

**Screenshot of PowerUsers, User Group**:
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

**Screenshot of Roles I created**:
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

**Screenshot of Example, policy used for Lambda for processing data from IoT Core and saving to DynamoDB**:
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

**Screenshot of Policies I created**:
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

Closed 2024-09-26.

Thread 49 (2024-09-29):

John Deere API integration Payload

asadmaza, 2024-09-29:
**Issue Description**
Need to create a test payload to see whether we can get the API integration tested at least.
We may not have enough time to setup a connection to the End Point.

**Current Plan:**
Test John Deere API by testing the current Asset API Endpoints using static test payloads.

1. Get all assets
2. Create a new asset - craft a payload to create new IoT Soil Moisture Sensor
3. Get a specific asset - craft a payload to get the information for the new asset created
4. Update an asset - update location and soil moisture data for this sensor
5. Delete an asset - delete this sensor

**Future Plan if I can complete the current Plan:**
1. Create a Lambda Function to automatically update the IoT Soil Moisture Sensor (triggered by new item added to DynamoDB).

Diagram below shows the design for the Lambda that will connect to the John Deere API End Point.
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

asadmaza, 2024-10-18:
Closing. Plan is still useful for how to setup and test then execute the John Deere API integration.

Closed 2024-10-18.

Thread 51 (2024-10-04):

BOM Data Integration for Testing

asadmaza, 2024-10-04:
I need to integrate BOM data hopefully into the dashboard so we can check ground truth values for weather conditions as LoRa signal quality metrics such as SNR, RSSI are affected by weather.

Not sure if I will get API access in time.

High level Plan:
1. Get API access from BOM Space Weather API
2. Find nearest weather station/location to UWA and the frequency of the data captured i.e. the time, whether hourly etc as weather conditions are dynamic and change frequently that could affect the readings.
3. See what weather data is available. Get Temperature, Humidity, Conditions/Radiation (if possible)
4. Use existing ProcessSoilMoisture Lambda to GET from BOM Space Weather API End Point for weather station/location to UWA. Then transform the data and append to JSON stored in DynamoDB
5. Update existing pipeline in AWS Quicksights

asadmaza, 2024-10-04:
**Step 1: BOM Space Weather API Registration**
- I navigated to the [BOM Space Weather API ](https://sws-data.sws.bom.gov.au/register)and registered for API access.
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

**Step 2: Test BOM API requests**
- Before I try to get the nearest weather station, I need to check whether I indeed have access so am attempting to run the API a few times via the online API request tool
- Ok upon checking the document and examples here. This is not what we need.

## Back to the drawing board

asadmaza, 2024-10-10:
My [research ](https://ieeexplore.ieee.org/document/9431229/)shows that ** temperature, rainfall, and solar radiation (UV?) are weather attributes that affect LoRa signal quality**.

BOM historical data can be manually downloaded and for more specific attributes, [data payment is required.](https://reg.bom.gov.au/climate/data-services/charges.shtml)

**Goal:** We need to integrate BOM historical Weather data (temperature, rainfall, and radiation).

Credit to Github user `tonyallan`.
I found BOM weather API structure [here.](https://github.com/tonyallan/weather-au/blob/master/weather_au/api.py)

### Please find proper API source going forward. This is just for testing purposes to show possibilities

### [1] Finding nearest Weather Station to Crawley (Testing Site)
- I queried the API to find the geohash for Crawley weather station is `qd6657p`
** Please find an alternative API source going forward. This is just for testing purposes**
**Output showing how I found the geohash for Crawley:**
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

### [2] Getting location data for Crawley Weather Station
- I queried another API to find the latitude (`-31.975021362304688`) and longitude (`115.81718444824219`) of the closest weather station to our testing site
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

API won't let me customise historical data. I'll go find a free/trial based free weather API end point.

## Back to the drawing board

asadmaza, 2024-10-18:
I found an alternative Weather API that I presented to Atif on 11th October during our final presentation.

[Open Meteo](https://open-meteo.com/en/docs/historical-weather-api) has all the requirement for API and it is free!

In the future this should be integrated within the Lambda Function that preprocesses data from [IoT Core and saves into DynamoDB](https://github.com/bellabaohaha/CITS5206-Gp2/issues/38)

From other task, regarding LoRa Communication, we can see that peer research shows, weather wise, the temperature and the direct solar radiation affects the signal quality. As the next steps in terms of testing would be to optimise the LoRa communication between Master Gateway and Sensor Board, we need to know how it varies with change in these uncontrollable weather conditions.

Current JSON structure in DynamoDB (comments are for descriptive purposes only, not in actual JSON):
```json
{
    "gateway_id": {  // Internet (Master) Gateway ID (Primary/Partition Key in DynamoDB)
      "S": "gt1"
    },
    "sensor_board_id_timestamp": {  // Sensor Board (Slave) Unique ID with timestamp on sensor board (Sort Key in DynamoDB)
      "S": "sb1_2024-10-04T15:46:56"
    },
    "gateway_latitude": {  // Internet (Master) Gateway Latitude coordinate
      "N": "-31.979476"
    },
    "gateway_longitude": { // Internet (Master) Gateway Longitude coordinate
      "N": "115.818473"
    },
    "gateway_timestamp": { // Internet (Master) Gateway timestamp on gateway board
      "S": "2024-10-04T15:46:50"
    },
    "sensor_board_battery_percentage": { // Internet (Master) Gateway Latitude coordinate
      "N": "99"
    },
    "sensor_board_depth1_in_cm": {  // Soil Moisture Sensor 1 depth in cm
      "N": "10"
    },
    "sensor_board_depth1_soil_moisture_percentage": {  // Soil Moisture Sensor 1 moisture %
      "N": "100"
    },
    "sensor_board_depth2_in_cm": {  // Soil Moisture Sensor 2 depth in cm
      "N": "20"
    },
    "sensor_board_depth2_soil_moisture_percentage": {  // Soil Moisture Sensor 2 moisture %
      "N": "100"
    },
    "sensor_board_depth3_in_cm": {  // Soil Moisture Sensor 2 depth in cm
      "N": "30"
    },
    "sensor_board_depth3_soil_moisture_percentage": {  // Soil Moisture Sensor 3 moisture %
      "N": "100"
    },
    "sensor_board_id": {  // Sensor Board (Slave) Unique ID
      "S": "sb1"
    },
    "sensor_board_latitude": {  // Sensor Board (Slave) Latitude coordinate
      "N": "-31.980473"
    },
    "sensor_board_longitude": { // Sensor Board (Slave) Longitude coordinate
      "N": "115.817200"
    },
    "sensor_timestamp": { // Sensor Board (Slave) timestamp on board
      "S": "2024-10-04T15:46:56"
    },
    "rssi": {  // Internet (Master) Gateway Received Signal Strength Indicator from Sensor Board (LoRa)
      "N": "-91"
    },
    "snr": { // Internet (Master) Gateway Signal to Noise Ratio from Sensor Board (LoRa)
      "N": "1.00"
    },
    "package_size": { // Internet (Master) Gateway Packet Size from Sensor Board (LoRa)
      "N": "72"
    }
  }
```

**Proposed JSON using Lambda to aggregate from IoT Core and Open Meteo (To be confirmed with Gustavo)**:
```json
{
    "gateway_id": {  // Internet (Master) Gateway ID (Primary/Partition Key in DynamoDB)
      "S": "gt1"
    },
    "sensor_board_id_timestamp": {  // Sensor Board (Slave) Unique ID with timestamp on sensor board (Sort Key in DynamoDB)
      "S": "sb1_2024-10-04T15:46:56"
    },
    "gateway_latitude": {  // Internet (Master) Gateway Latitude coordinate
      "N": "-31.979476"
    },
    "gateway_longitude": { // Internet (Master) Gateway Longitude coordinate
      "N": "115.818473"
    },
    "gateway_timestamp": { // Internet (Master) Gateway timestamp on gateway board
      "S": "2024-10-04T15:46:50"
    },
    "sensor_board_battery_percentage": { // Internet (Master) Gateway Latitude coordinate
      "N": "99"
    },
    "sensor_board_depth1_in_cm": {  // Soil Moisture Sensor 1 depth in cm
      "N": "10"
    },
    "sensor_board_depth1_soil_moisture_percentage": {  // Soil Moisture Sensor 1 moisture %
      "N": "100"
    },
    "sensor_board_depth2_in_cm": {  // Soil Moisture Sensor 2 depth in cm
      "N": "20"
    },
    "sensor_board_depth2_soil_moisture_percentage": {  // Soil Moisture Sensor 2 moisture %
      "N": "100"
    },
    "sensor_board_depth3_in_cm": {  // Soil Moisture Sensor 2 depth in cm
      "N": "30"
    },
    "sensor_board_depth3_soil_moisture_percentage": {  // Soil Moisture Sensor 3 moisture %
      "N": "100"
    },
    "sensor_board_id": {  // Sensor Board (Slave) Unique ID
      "S": "sb1"
    },
    "sensor_board_latitude": {  // Sensor Board (Slave) Latitude coordinate
      "N": "-31.980473"
    },
    "sensor_board_longitude": { // Sensor Board (Slave) Longitude coordinate
      "N": "115.817200"
    },
    "sensor_timestamp": { // Sensor Board (Slave) timestamp on board
      "S": "2024-10-04T15:46:56"
    },
    "rssi": {  // Internet (Master) Gateway Received Signal Strength Indicator from Sensor Board (LoRa)
      "N": "-91"
    },
    "snr": { // Internet (Master) Gateway Signal to Noise Ratio from Sensor Board (LoRa)
      "N": "1.00"
    },
    "package_size": { // Internet (Master) Gateway Packet Size from Sensor Board (LoRa)
      "N": "72"
    },
    "hourly_average_temperature": { // Temperature (degrees Celsius) for the hour (Open Meteo API GET)
      "N": "16.4"
    },
    "hourly_direct_solar_radiation": { // Direct Solar Radiation (W/m^2) for the hour (Open Meteo API GET)
      "N": "138"
    }
  }
```

Open Meteo Settings for API testing (10,000 API calls a day for non-commercial purposes):
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

Open Meteo GET Request Example based on Settings above Link [here](https://archive-api.open-meteo.com/v1/archive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)

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

Closing but will provide simple next steps:
1. Confirm which variables and type of measurement are most important with Gustavo i.e. mean temperature, maximum temperature, minimum temperature, other variables like rainfall?
2. What resolution is best for API calls i.e. 2 minute interval, daily interval when adding into DB (should we use daily average, or should we use closest 2 min interval when processing data from IoT Core)
3. Update JSON if required
4. Update Lambda for AWS IoT Core to DynamoDB such that we have the new JSON Structure
5. Test Lambda for AWS IoT Core payload to DynamoDB entry
6. Deploy Lambda
7. Test in UWA, get feedback, optimise
9. Test on Site, get feedback, optimise

asadmaza, 2024-10-18:
Renamed from BOM Data Integration for Testing to Meteo Data Integration for Testing

Closed 2024-10-18.

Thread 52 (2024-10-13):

Gateway Setup

David-Shang, 2024-10-13:

David-Shang, 2024-10-13:
# Gateway Configuration and Setup

Here are all the libraries needed for use in the Gateway:
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

It is important to note that XPowersLib should use version 0.2.5, not the latest version 0.2.6.

The Gateway code consists of the following files:

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

Among these, GatewayTest.ino is the main file, while the others are configuration files. The user needs to create a local `Secrets.h` file to store the relevant AWS IoT Core configuration keys and Wi-Fi connection details (username, password).

# AWS IoT Core Configuration and Setup

First, create an object in Thing, and be sure to save the relevant keys and certificates during creation:

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

Then, create a subscription and bookmark it in the MQTT test client to receive the transmitted data.

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

asadmaza, 2024-10-18:
Closing as completed documentation for setup and testing of AWS IoT Core component.

This was based off the tutorial hyperlinked in our project specification report in "MQTT". If required feel free to look at our project specification Document [here](https://docs.google.com/document/d/e/2PACX-1vQgFZYsjV_GxjA3R-3JgrfRtF1S1AyGVZv23MqUZeG_EGrN42N-DA0dy9TNv7VEn3zz4qyqGnXIjelU/pub)

Also for handy access, specific tutorial [here](https://how2electronics.com/connecting-esp32-to-amazon-aws-iot-core-using-mqtt/) for connecting ESP 32 based boards.

Closed 2024-10-18.

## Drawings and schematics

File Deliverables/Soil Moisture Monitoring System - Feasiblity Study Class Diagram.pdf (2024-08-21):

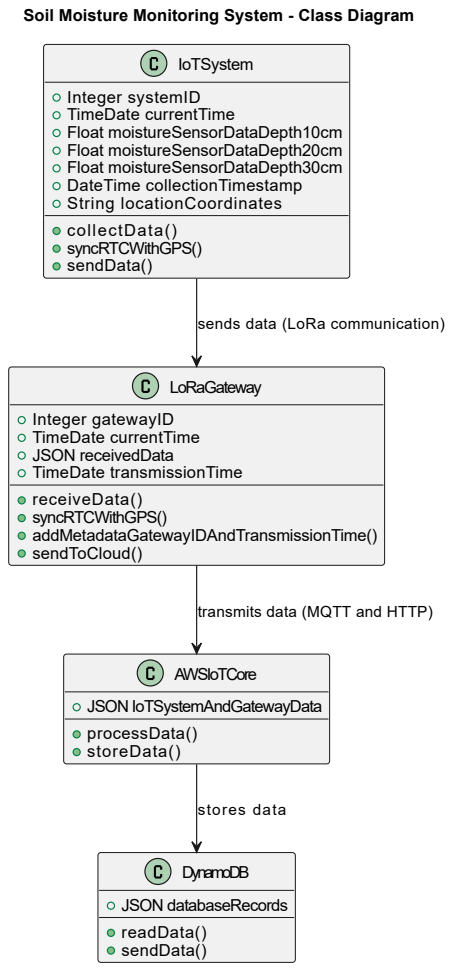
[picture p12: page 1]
IoTSystem; Integer systemID TimeDate currentTime Float moistureSensorDataDepth10cm Float moistureSensorDataDepth20cm Float moistureSensorDataDepth30cm DateTime collectionTimestamp String locationCoordinates collectData() syncRTCWithGPS() sendData(); LoRaGateway; Integer gatewayID TimeDate currentTime JSON receivedData TimeDate transmissionTime receiveData() syncRTCWithGPS() addMetadataGatewayIDAndTransmissionTime() sendToCloud(); AWSIoTCore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

Soil Moisture Monitoring System - Class Diagram

sends data (LoRa communication)

transmits data (MQTT and HTTP)

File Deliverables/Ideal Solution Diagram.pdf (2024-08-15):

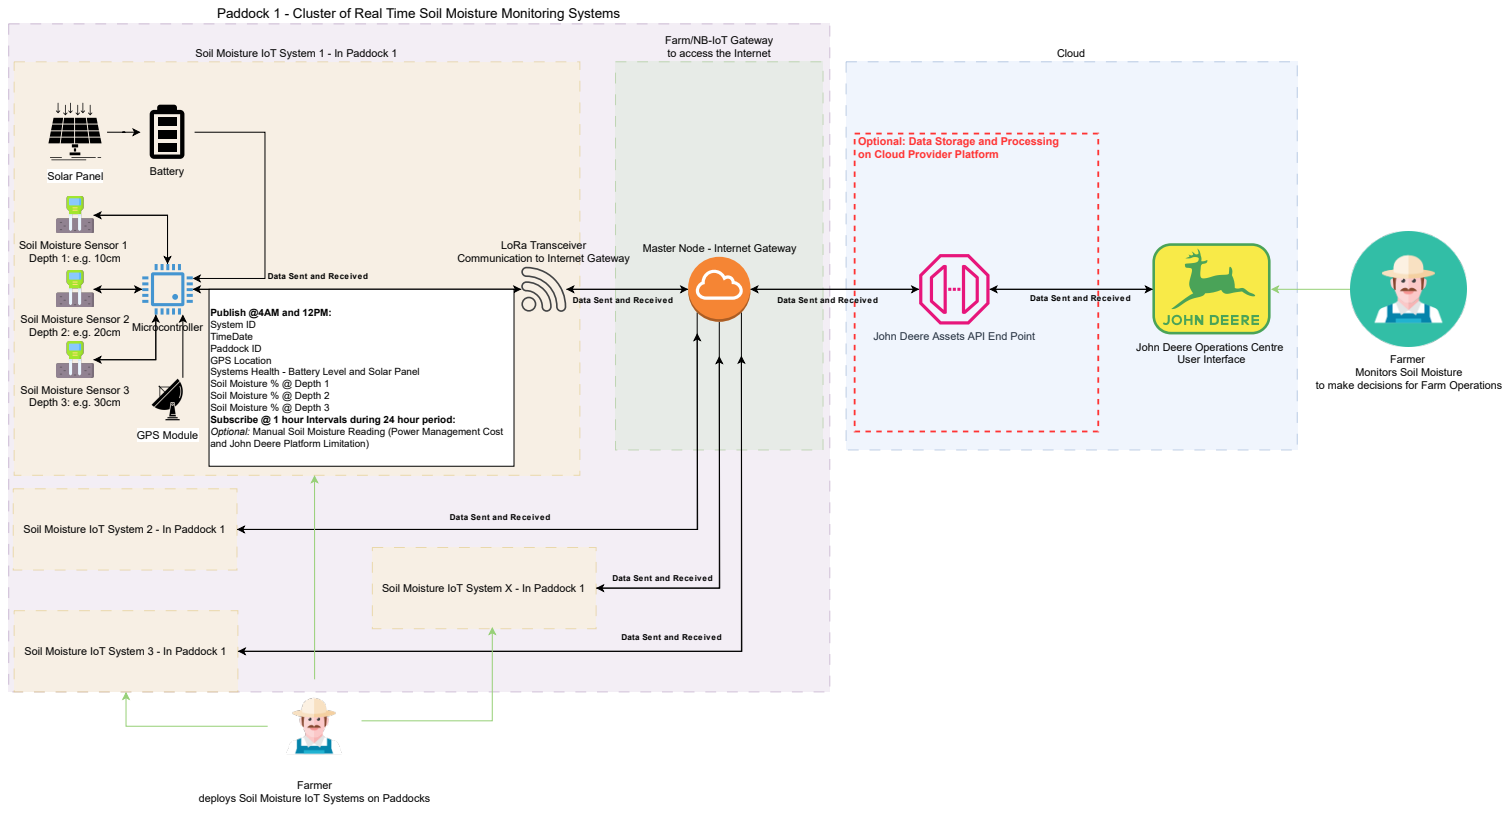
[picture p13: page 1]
Cloud; Soil Moisture IoT System 1 - In Paddock 1; to access the Internet; Microcontroller; User Interface; GPS Module; Farmer; Data Sent and Received; LoRa Transceiver

Paddock 1 - Cluster of Real Time Soil Moisture Monitoring Systems

Farm/NB-IoT Gateway

Optional: Data Storage and Processing
on Cloud Provider Platform

Battery Solar Panel

Soil Moisture Sensor 1
Depth 1: e.g. 10cm

Master Node - Internet Gateway

Communication to Internet Gateway

Data Sent and Received

Soil Moisture Sensor 2
Depth 2: e.g. 20cm

Publish @4AM and 12PM:
System ID
TimeDate
Paddock ID
GPS Location
Systems Health - Battery Level and Solar Panel
Soil Moisture % @ Depth 1
Soil Moisture % @ Depth 2
Soil Moisture % @ Depth 3
Subscribe @ 1 hour Intervals during 24 hour period:
Optional: Manual Soil Moisture Reading (Power Management Cost
and John Deere Platform Limitation)

John Deere Assets API End Point

John Deere Operations Centre

Farmer
Monitors Soil Moisture

Soil Moisture Sensor 3
Depth 3: e.g. 30cm

to make decisions for Farm Operations

Soil Moisture IoT System 2 - In Paddock 1

Soil Moisture IoT System X - In Paddock 1

Soil Moisture IoT System 3 - In Paddock 1

deploys Soil Moisture IoT Systems on Paddocks

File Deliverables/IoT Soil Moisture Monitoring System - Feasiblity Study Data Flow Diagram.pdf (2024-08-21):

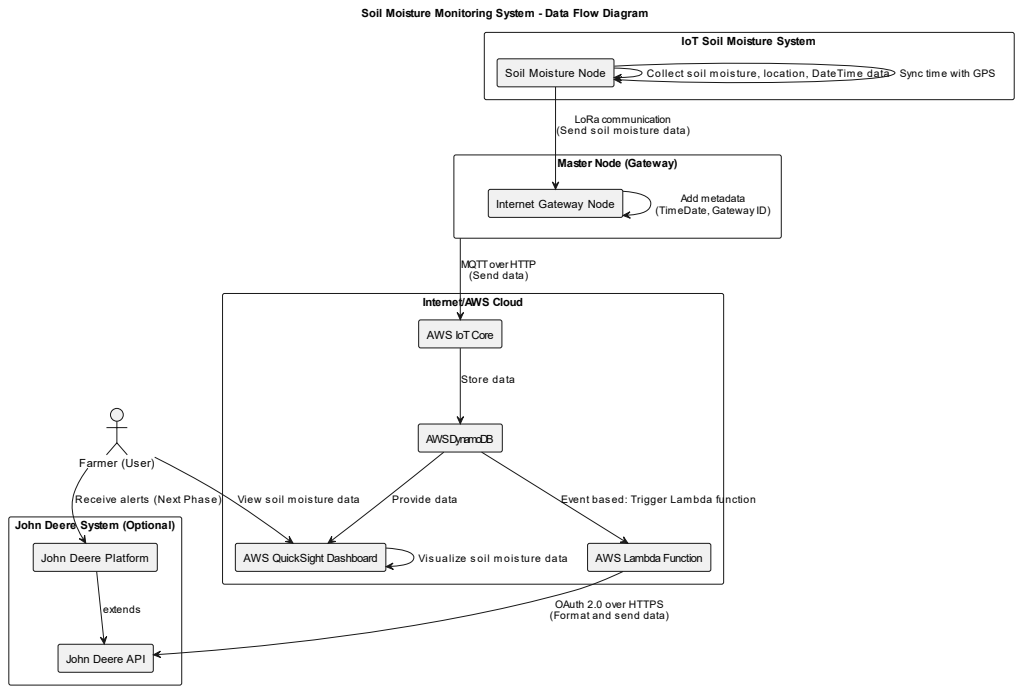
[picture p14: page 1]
AWS DynamoDB; AWS QuickSight Dashboard; AWS Lambda Function; Farmer (User); Store data; Provide data; Event based: Trigger Lam bda function; extends; OAuth 2.0 over HTTPS; Receive alerts (Next Phas e); View soil m oisture data

Soil Moisture Monitoring System - Data Flow Diagram

IoT Soil Moisture System

Soil Moisture Node

Collect s oil m ois ture, location, DateTim e data Sync time with GPS

LoRa communication
(Send s oil m ois ture data)

Master Node (Gateway)

Internet Gateway Node

Add metadata
(TimeDate, Gateway ID)

MQTT over HTTP
(Send data)

Internet/AWS Cloud

AWS IoT Core

John Deere System (Optional)

John Deere Platform

Vis ualize s oil m ois ture data

(Format and send data)

John Deere API

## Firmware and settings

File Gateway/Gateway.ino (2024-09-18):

#include "secrets.h"
#include <WiFiClientSecure.h>
#include <PubSubClient.h>
#include <ArduinoJson.h>
#include "WiFi.h"

// Define AWS IoT topic
#define AWS_IOT_PUBLISH_TOPIC   "esp32/pub"
#define AWS_IOT_SUBSCRIBE_TOPIC "esp32/sub"

// WiFi and MQTT client setup
WiFiClientSecure net = WiFiClientSecure();
PubSubClient client(net);

// Wi-Fi connection function with timeout
void connectToWiFi() {
  WiFi.mode(WIFI_STA);
  WiFi.begin(WIFI_SSID, WIFI_PASSWORD);
  
  Serial.println("Connecting to Wi-Fi");

  int retries = 0;
  int maxRetries = 20; // Wait for 10 seconds (20 * 500ms)

  while (WiFi.status() != WL_CONNECTED && retries < maxRetries) {
    delay(500);
    Serial.print(".");
    retries++;
  }

  if (WiFi.status() == WL_CONNECTED) {
    Serial.println("\nWi-Fi connected successfully!");
    Serial.print("IP Address: ");
    Serial.println(WiFi.localIP());
  } else {
    Serial.println("\nFailed to connect to Wi-Fi, restarting...");
    ESP.restart(); // Restart ESP32 if Wi-Fi connection fails
  }
}

void connectAWS()
{
  connectToWiFi(); // Ensure Wi-Fi is connected before proceeding

  // Configure WiFiClientSecure to use the AWS IoT device credentials
  net.setCACert(AWS_CERT_CA);
  net.setCertificate(AWS_CERT_CRT);
  net.setPrivateKey(AWS_CERT_PRIVATE);

  // Connect to the MQTT broker on the AWS endpoint we defined earlier
  client.setServer(AWS_IOT_ENDPOINT, 8883);

  // Create a message handler
  client.setCallback(messageHandler);

  Serial.println("Connecting to AWS IOT");

  while (!client.connect(THINGNAME))
  {
    Serial.print(".");
    delay(100);
  }

  if (!client.connected())
  {
    Serial.println("AWS IoT Timeout!");
    return;
  }

  // Subscribe to a topic
  client.subscribe(AWS_IOT_SUBSCRIBE_TOPIC);

  Serial.println("AWS IoT Connected!");
}

void publishMessage()
{
  if (client.connected()) {

    // StaticJsonDocument<512> doc;

    // doc["sb"]["ID"] = "sb1";
    // doc["sb"]["date"] = "2024-09-12";
    // doc["sb"]["time"] = "12:34:56";
    // doc["sb"]["GPS"] = "51.5074, 0.1278";
    // doc["sb"]["battery"] = "75%";

    
    // doc["s1"]["depth"] = 10;
    // doc["s1"]["water"] = 10;

    // doc["s2"]["depth"] = 30;
    // doc["s2"]["water"] = 55;

    // doc["s3"]["depth"] = 50;
    // doc["s3"]["water"] = 60;

    // doc["gt"]["ID"] = "gt1";
    // doc["gt"]["date"] = "2024-09-12";
    // doc["gt"]["time"] = "12:34:56";
    // doc["gt"]["GPS"] = "51.5074, 0.1278";
    // doc["gt"]["battery"] = "80%";

    StaticJsonDocument<512> doc;

    JsonArray array = doc.to<JsonArray>();

    // Sensor board data
    array.add("sb1");             // Sensor board ID
    array.add("2024-09-12");       // Sensor board date
    array.add("12:34:56");         // Sensor board time
    array.add("51.5074, 0.1278");  // Sensor board GPS
    array.add("75%");              // Sensor board battery

    // Sensor 1 data
    array.add(10);                 // Sensor 1 depth, Could be delete
    array.add(10);                 // Sensor 1 water level

    // Sensor 2 data
    array.add(30);                 // Sensor 2 depth, Could be delete
    array.add(55);                 // Sensor 2 water level

    // Sensor 3 data
    array.add(50);                 // Sensor 3 depth, Could be delete
    array.add(60);                 // Sensor 3 water level

    // Gateway data
    array.add("gt1");              // Gateway ID
    array.add("2024-09-12");       // Gateway date
    array.add("12:34:56");         // Gateway time
    array.add("51.5074, 0.1278");  // Gateway GPS
    array.add("80%");              // Gateway battery

    char jsonBuffer[512];
    serializeJson(doc, jsonBuffer); // Convert the JSON object to a string

    delay(1000); // Allow a moment before attempting to publish

    Serial.print("Publishing message: ");
    Serial.println(jsonBuffer);

    if (client.publish(AWS_IOT_PUBLISH_TOPIC, jsonBuffer)) {
      Serial.println("Message successfully published.");
    } else {
      Serial.print("Failed to publish message, error code: ");
      Serial.println(client.state());
    }
  } else {
    Serial.println("Client is not connected to AWS IoT.");
  }
}


void messageHandler(char* topic, byte* payload, unsigned int length)
{
  Serial.print("incoming: ");
  Serial.println(topic);

  StaticJsonDocument<200> doc;
  deserializeJson(doc, payload);
  const char* message = doc["message"];
  Serial.println(message);
}

void setup()
{
  Serial.begin(115200);
  
  // Connect to AWS IoT and send the message
  connectAWS();
  publishMessage();
  
  // Close the connection after sending the message
  Serial.println("Data sent once, stopping further execution.");
}

void loop()
{
  // Nothing here, no need to loop
}

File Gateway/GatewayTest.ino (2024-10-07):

#include <Wire.h>
#include <TinyGPS++.h>
#include <HardwareSerial.h>
#include <LoRa.h>
#include "LoRaBoards.h"
#include "secrets.h"
#include <WiFiClientSecure.h>
#include <PubSubClient.h>
#include <ArduinoJson.h>
#include "WiFi.h"

// Constants for LoRa
#ifndef CONFIG_RADIO_FREQ
#define CONFIG_RADIO_FREQ           915.0
#endif
#ifndef CONFIG_RADIO_OUTPUT_POWER
#define CONFIG_RADIO_OUTPUT_POWER   17
#endif
#ifndef CONFIG_RADIO_BW
#define CONFIG_RADIO_BW             125.0
#endif

#if !defined(USING_SX1276) && !defined(USING_SX1278)
#error "LoRa example is only allowed to run SX1276/78. For other RF models, please run examples/RadioLibExamples"
#endif

// GPS object
TinyGPSPlus gps;
HardwareSerial GPS(1);

// Define AWS IoT topic
#define AWS_IOT_PUBLISH_TOPIC   "esp32/pub"
#define AWS_IOT_SUBSCRIBE_TOPIC "esp32/sub"

// WiFi and MQTT client setup
WiFiClientSecure net = WiFiClientSecure();
PubSubClient client(net);

// Variables
String gpsData[4]; // [0] = "gt1", [1] = Latitude, [2] = Longitude, [3] = Time (HH:MM:SS)

void setup() {
    setupBoards();
    delay(1500);

    Serial.begin(115200);
    Serial.println("LoRa Receiver");

    // Initialize Wi-Fi and AWS IoT connection
    connectAWS();

    // Initialize LoRa
#ifdef RADIO_TCXO_ENABLE
    pinMode(RADIO_TCXO_ENABLE, OUTPUT);
    digitalWrite(RADIO_TCXO_ENABLE, HIGH);
#endif

    LoRa.setPins(RADIO_CS_PIN, RADIO_RST_PIN, RADIO_DIO0_PIN);
    if (!LoRa.begin(CONFIG_RADIO_FREQ * 1000000)) {
        Serial.println("Starting LoRa failed!");
        while (1);
    }

    LoRa.setTxPower(CONFIG_RADIO_OUTPUT_POWER);
    LoRa.setSignalBandwidth(CONFIG_RADIO_BW * 1000);
    LoRa.setSpreadingFactor(10);
    LoRa.setPreambleLength(16);
    LoRa.setSyncWord(0xAB);
    LoRa.disableCrc();
    LoRa.disableInvertIQ();
    LoRa.setCodingRate4(7);

    // Start listening for incoming packets
    LoRa.receive();

    // Initialize GPS
    GPS.begin(9600, SERIAL_8N1, 34, 12); // GPS uses TX=12, RX=34
    delay(15000);  // Wait for GPS to stabilize
}

void connectToWiFi() {
    WiFi.mode(WIFI_STA);
    WiFi.begin(WIFI_SSID, WIFI_PASSWORD);
    
    Serial.println("Connecting to Wi-Fi");

    int retries = 0;
    int maxRetries = 20; // Wait for 10 seconds (20 * 500ms)

    while (WiFi.status() != WL_CONNECTED && retries < maxRetries) {
        delay(500);
        Serial.print(".");
        retries++;
    }

    if (WiFi.status() == WL_CONNECTED) {
        Serial.println("\nWi-Fi connected successfully!");
        Serial.print("IP Address: ");
        Serial.println(WiFi.localIP());
    } else {
        Serial.println("\nFailed to connect to Wi-Fi, restarting...");
        ESP.restart(); // Restart ESP32 if Wi-Fi connection fails
    }
}

void connectAWS() {
    connectToWiFi(); // Ensure Wi-Fi is connected before proceeding

    // Configure WiFiClientSecure to use the AWS IoT device credentials
    net.setCACert(AWS_CERT_CA);
    net.setCertificate(AWS_CERT_CRT);
    net.setPrivateKey(AWS_CERT_PRIVATE);

    // Connect to the MQTT broker on the AWS endpoint
    client.setServer(AWS_IOT_ENDPOINT, 8883);

    Serial.println("Connecting to AWS IOT");

    while (!client.connect(THINGNAME)) {
        Serial.print(".");
        delay(100);
    }

    if (!client.connected()) {
        Serial.println("AWS IoT Timeout!");
        return;
    }

    // Subscribe to a topic
    client.subscribe(AWS_IOT_SUBSCRIBE_TOPIC);
    Serial.println("AWS IoT Connected!");
}

void storeGPSData() {
    // Store "gt1" in the first element
    gpsData[0] = "gt1";
    
    // Store GPS data into the array as a single string
    gpsData[1] = String(gps.location.lat(), 6);  // Latitude
    gpsData[2] = String(gps.location.lng(), 6);  // Longitude

    // Print received GPS coordinates
    Serial.print("Storing Latitude: "); Serial.println(gpsData[1]);
    Serial.print("Storing Longitude: "); Serial.println(gpsData[2]);


    // Print received time
    if (gps.time.isValid()) {
        // Format time as "HH:MM:SS"
        String timeString = String(gps.time.hour() + 8) + ":" + String(gps.time.minute()) + ":" + String(gps.time.second());
        gpsData[3] = timeString; // Store formatted time
        Serial.print("Storing Time (HH:MM:SS): ");
        Serial.println(gpsData[3]);
    } else {
        gpsData[3] = "00:00:00"; // Set to default if time is not valid
        Serial.println("Invalid GPS time.");
    }
}

void publishMessage(const String& combinedArray) {
    if (client.connected()) {
        StaticJsonDocument<512> doc;

        JsonArray array = doc.to<JsonArray>();

        // Split the combined array into components
        int index = 0;
        String part;
        String tempCombinedArray = combinedArray;
        while (tempCombinedArray.indexOf(',') != -1) {
            part = tempCombinedArray.substring(0, tempCombinedArray.indexOf(','));
            array.add(part);
            tempCombinedArray.remove(0, tempCombinedArray.indexOf(',') + 1);
        }
        array.add(tempCombinedArray); // Add the last part

        // Serialize the JSON document to a String
        String jsonBuffer;
        serializeJson(doc, jsonBuffer); // Serialize into the String

        delay(1000); // Allow a moment before attempting to publish

        Serial.print("Publishing message: ");
        Serial.println(jsonBuffer);

        if (client.publish(AWS_IOT_PUBLISH_TOPIC, jsonBuffer.c_str())) { // Use c_str() to get a C-style string
            Serial.println("Message successfully published.");
        } else {
            Serial.print("Failed to publish message, error code: ");
            Serial.println(client.state());
        }
    } else {
        Serial.println("Client is not connected to AWS IoT.");
    }
}
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

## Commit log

2024-08-21 Adding generated data and Prototype dashboard
    [mock_gateway_data.csv, mock_soil_moisture_data.csv]
2024-08-21 Add circuit diagram
    Add circuit diagram
2024-08-21 Created Soil Moisture IoT Prototype and LoRa Gateway Prototype Diagrams
    [LoRa Gateway Prototype.fzz, Soil Moisture IoT Prototype.fzz]
2024-09-20 added quicksight prototype
2024-09-20 added 100 rows of mock data
    [smart_soil_moisture_monitor_sample_expanded.csv]
